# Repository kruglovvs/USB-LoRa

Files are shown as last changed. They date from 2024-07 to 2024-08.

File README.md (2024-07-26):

# USB-LoRa приёмопередатчик 
Это моя курсовая работа на 3 курсе МГТУ по направлению "Конструирование и технология электронных средств". Устройство передаёт данные между LoRa передачаей и USB COM терминалом.
Работает на основе микроконтроллера STM32WLE5CCU6. Имеет собственную PCB-антенну, разработанную в HFSS. Из-за малых габаритов антенна имеет плохой S-параметр и малую мощность, но вполне достаточную для LoRa передачи.
Габариты печатной платы соответсвуют распространённому дешёвому USB корпусу G1901C.

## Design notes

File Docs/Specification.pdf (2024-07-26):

Перв. примен.

ИУ4.11.03.03.21.63.14.001

Формат
Зона
Поз.
Обозначение | Наименование | Кол. | Примечание
| Документация
А3 | ИУ4.11.03.03.21.63.14.001 СБ | Сборочный чертёж
А3 | ИУ4.11.03.03.21.63.14.001 Э1 | Схема электрическая структурная
А3 | ИУ4.11.03.03.21.63.14.001 Э2 | Схема электрическая функциональная
А3 | ИУ4.11.03.03.21.63.14.001 Э3 | Схема электрическая принципиальная
А4 | ИУ4.11.03.03.21.63.14.001 ПЭ3 | Перечень элементов

Справ. N

А3 | ИУ4.11.03.03.21.63.14.001 ПД1 | Алгоритм работы устройства
А3 | ИУ4.11.03.03.21.63.14.001 ПД1 | Плакат демонстрационный
А2 | ИУ4.11.03.03.23.05.53.12.002 | Плата печатная

Детали

1 | ИУ4.11.03.03.23.05.53.12.002 | Плата печатная | 1

Прочие изделия

Чип-конденсаторы керамические

2 | К10-16В-5,1пФ1 ±5%(Murata, Япония) | 2 | С1,C2
3 | К10-16В-100нФ±10%(Murata, Япония) | 10 | C3,C16…С18,C25
Подп. и дата
C20…C23,C27
4 | К10-16В-4.7мкФ±10%(Murata, Япония) | 5 | C6,C12...C14
5 | К10-16В-47нФ±5%(Murata, Япония) | 1 | C4
6 | К10-16В-3.6пФ±5%(Murata, Япония) | 1 | C5
Инв. N дубл.
7 | К10-16В-68нФ±5%(Murata, Япония) | 3 | C7,C15,C30
8 | К10-16В-6.2пФ±5%(Murata, Япония) | 1 | C8
9 | К10-16В-4пФ±5%(Murata, Япония) | 1 | С9
Взаим. инв. N
10 | К10-16В-3.3пФ±5%(Murata, Япония) | 1 | С10
11 | К10-16В-2.4пФ±5%(Murata, Япония) | 2 | С11,C19
12 | К10-16В-0.47мкФ±10%(Murata, Япония) | 1 | C24

Подп. u дата

13 | К10-16В-33пФ±10%(Murata, Япония) | 3 | C26,C28,C29

ИУ4.11.03.03.21.63.14.001
Изм | Лист | № докум. | Подп. | Дата

Инв. N подп.

Разраб. Круглов В. С.

## LoRa-USB адаптер

спецификация

Лит. | Лист | Листов
Пров. | Чистяков М. Г. | 1 | 2
МГТУ им. Н. Э. Баумана
Кафедра ИУ4
Группа ИУ4-63Б

Н.контр.
Утв.

Формат
Зона
Поз.
Обозначение | Наименование | Кол. | Примечание
| Чип-резисторы толстоплёночные
14 | C2-0,125Вт-33Ом±10%(Yageo, Китай) | 2 | R1,R2
15 | С2-0,125Вт-10кОм±10%(Yageo, Китай) | 2 | R3,R4
16 | C2-0,125Вт-22кОм±10%(Yageo, Китай) | 1 | R5
17 | C2-0,125Вт-47кОм±10%(Yageo, Китай) | 3 | R6,R7,R8

Чип-индукторы многослойные

18 | LQG15HN2N6J (Murata, Япония) | 1 | L1
19 | LQG15HN11NJ (Murata, Япония) | 1 | L2
20 | LQG15HN47NJ (Murata, Япония) | 1 | L3
21 | LQG15HN1N8J (Murata, Япония) | 1 | L4
22 | LQG15HN7NJ (Murata, Япония) | 1 | L5
23 | LQG15HN150J (Murata, Япония) | 1 | L6
24 | Светодиоды
25 | TO-2106BC-MGD (OASISTEK, Китай) | 1 | VD1
| TO-2106BC-MRF (OASISTEK, Китай) | 1 | VD2

Подп. и дата

Микросхемы

26 | SRV05-4.TCT (Semtech, США) | 1 | DA1
Инв. N дубл.
27 | SRDA3.3-4DR2G (Onsemi, США) | DA2
28 | XC6219B332MR (UMW, Китай) | DA3
29 | HMC544AETR (Analog Devices, США) | DA4
Взаим. инв. N
30 | CP2102N-GQFN28R (Silicon Laboratories, США) | DD1
31 | STM32WLE5CCU6 (STMicroelectrionics, США) | DD2

Подп. u дата

32 | Кварцевый резонатор | ZQ1
33 | XRCGB16M000FXN02R0 (Murata, Япония) | XP1

Штекер USB-A PL-4 (Molex, США)

Инв. N подп.
ИУ4.11.03.03.21.63.14.001

Лист

2 Изм | Лист | № докум. | Подп. | Дата

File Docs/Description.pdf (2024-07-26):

Инв.№ подл. Подп.и дата Взам.инв.№ Инв.№ дубл. Подп. и дата

Формат A3 Справ.№ Перв.примен.

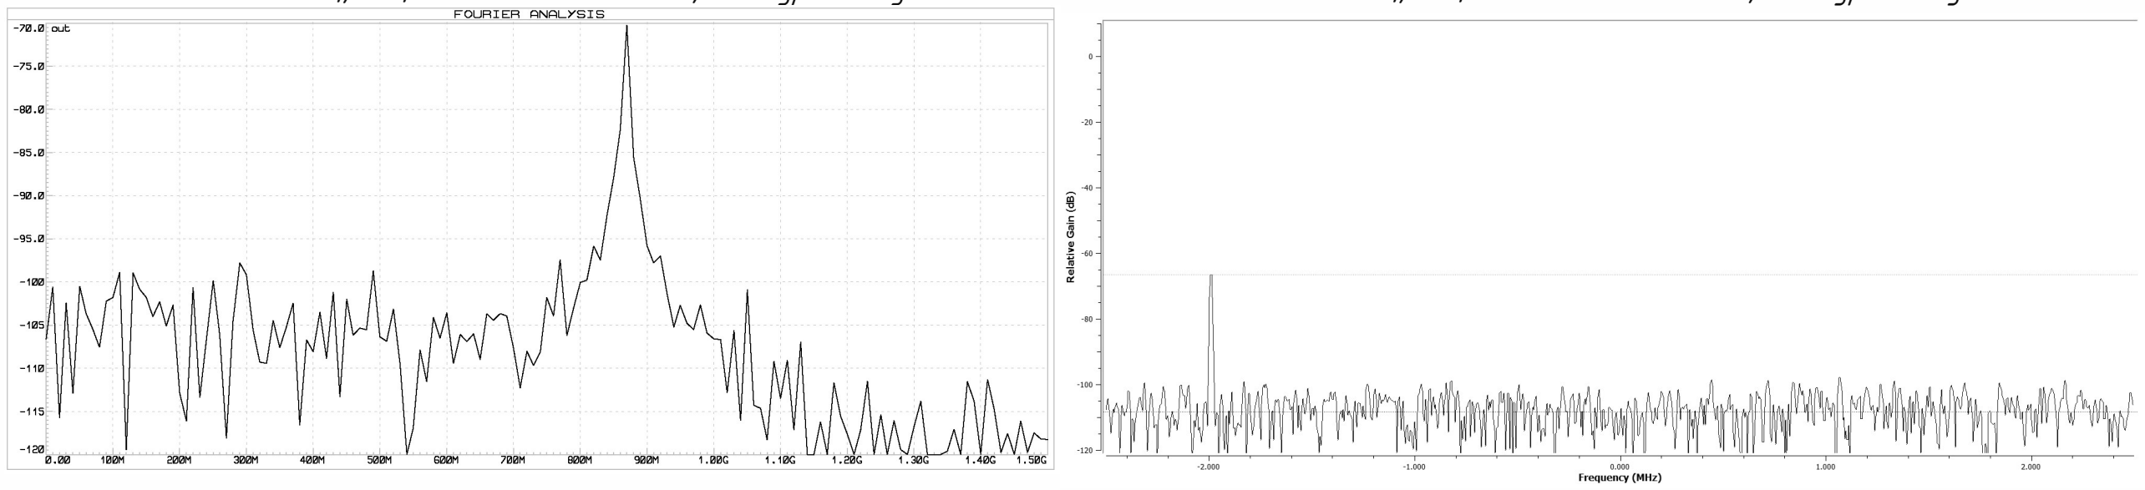
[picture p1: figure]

Н.контр.
Утв.
Копировал
| | | | | ИУ4.11.03.03.21.63.14.001 ПД2
| | | | | LoRa-USB адаптер Плакат демонстрационный | Лит. | Масштаб | Масса
Изм. | Лист | № докум. | Подп. | Дата
Разраб. | | Круглов В. С.
Пров. | | Чистяков М. Г.
Т.контр. | | | | | Лист | Листов 1
| | | | | МГТУ им. Н. Э. Баумана Кафедра ИУ4 Группа ИУ4-63Б

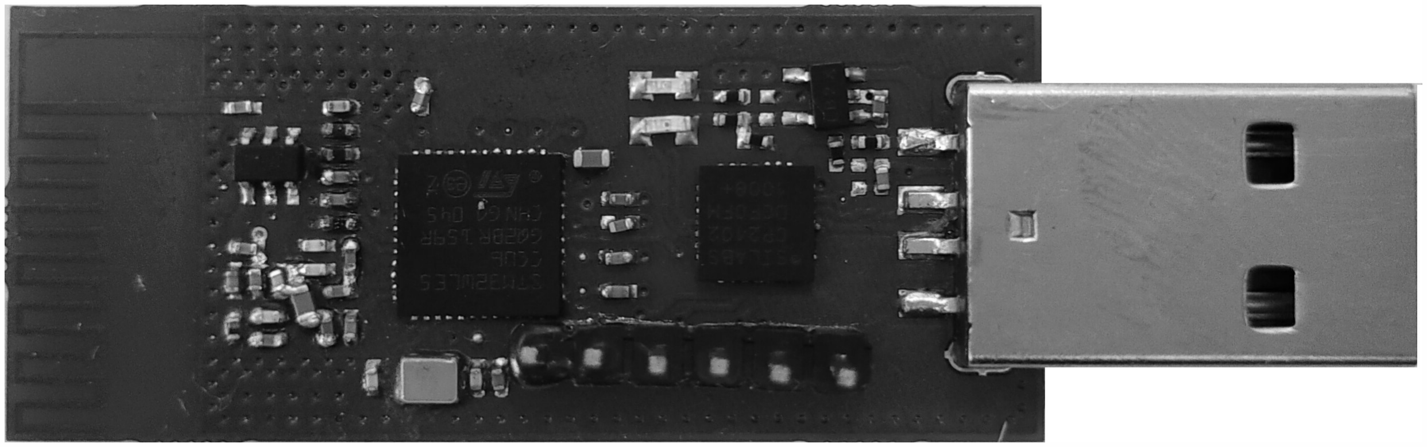
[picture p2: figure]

Итоговое устройство

Измеренная спектрограмма при отправке сигнала

через последовательный порт

## Вывод: результаты работы соответсвуют результатам моделирования, данные передаются между USB и LoRa, прототип соответсвует ТЗ

Частота сигнала 868МГц, мощность сигнала -70дБм, выше уровня шума на 30дБ Частота сигнала 868МГц, мощность сигнала -65дБм, выше уровня шума на 35дБ

Теоретическая спектрограмма при отправке сигнала
Диапазон 0...1500МГц | Ширина диапазона 5МГц, центральная частота 890 МГц, расстояние 1м

Для радиопередачи через LoRa достаточно,

## чтобы уровень сигнала была не ниже, чем на 20дБ уровня шума. Измеренный сигнал на

часототе 868МГц выше уровня шума на 35дБ,

## чего достаточно для передачи, что видно из вывода на терминале общения через последовательный порт

Окно терминала общения

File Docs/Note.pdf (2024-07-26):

Министерство науки и высшего образования Российской Федерации Федеральное государственное бюджетное образовательное учреждение высшего образования
«Московский государственный технический университет имени Н.Э. Баумана
(национальный исследовательский университет)» (МГТУ им. Н.Э. Баумана)
ФАКУЛЬТЕТ | «ИНФОРМАТИКА И СИСТЕМЫ УПРАВЛЕНИЯ» (ИУ)
КАФЕДРА | «ПРОЕКТИРОВАНИЕ И ТЕХНОЛОГИЯ ПРОИЗВОДСТВА ЭА» (ИУ4)

## РАСЧЕТНО-ПОЯСНИТЕЛЬНАЯ ЗАПИСКА

## К КУРСОВОЙ РАБОТЕ

## НА ТЕМУ:

## «Разработка, моделирование и экспериментальное исследование устройства LoRa-USB адаптера»

Студент | _________________ | Круглов В. С.
| (Подпись, дата)
Руководитель курсового проекта | _________________ | Чистяков М. Г.
| (Подпись, дата)

Москва, 2024

АННОТАЦИЯ

В рамках данной курсовой работы был разработан комплект

конструкторской документации для устройства «LoRa-USB адаптер». Описаны

принципы | работы | устройства, | обоснован | выбор | элементной | базы.

Спроектирована топология печатной платы в САПР Altium Designer 24 и

сборочный чертеж устройства. Проведено моделирование работы устройства в

САПР Proteus.

В результате работы получено полностью работоспособное устройство,

разработана принципиальная схема устройства, собран макетный образец,

проведены экспериментальные исследования его функциональных параметров и

сравнение параметров работы устройства с параметрами, полученными при

моделировании.

Ключевые слова: микроконтроллер, радиопередача, LoRa, USB, UART.

ABSTRACT

As part of this course work, a set of design documentation for the "LoRa-USB

adapter" device was developed. The principles of operation of the device are described,

the choice of the element base is justified. The topology of the printed circuit board in

CAD Altium Designer 24 and the assembly drawing of the device are designed. The

simulation of the device operation in the Proteus CAD is carried out.

As a result of the work, a fully functional device was obtained, a schematic

diagram of the device was developed, a mock-up sample was assembled, experimental

studies of its functional parameters were carried out and the parameters of the device

operation were compared with the parameters obtained during modeling.

Keywords: microcontroller, radiotraffic, LoRa, USB, UART.

СОДЕРЖАНИЕ

### 3 РАЗРАБОТКА СТРУКТУРНОЙ СХЕМЫ УСТРОЙСТВА “LORA-USB

### 4 РАЗРАБОТКА ФУНКЦИОНАЛЬНОЙ СХЕМЫ «LORA-USB АДАПТЕР»

### 8 РАЗРАБОТКА СБОРОЧНОГО ЧЕРТЕЖА И СПЕЦИФИКАЦИИ

9 | РАЗРАБОТКА | ПРОГРАММНОГО | ОБЕСПЕЧЕНИЯ“LORA-USB

УСЛОВНЫЕ ОБОЗНАЧЕНИЯ, СОКРАЩЕНИЯ И ТЕРМИНЫ

ГОСТ | − Государственный стандарт
ВАХ | − Вольт-амперная характеристика
КМО | − Компонент, монтируемый в отверстия
КМП | − Компонент, монтируемый на поверхности
ДПП | − Двухсторонняя печатная плата
МК | − Микроконтроллер
САПР | − Система автоматизированного проектирования
ОУ | − Операционный усилитель
ПК | − Персональный компьютер
ПО | − Программное обеспечение
ПП | − Печатная плата
СБ | − Сборочный чертеж
СП | − Спецификация
УГО | − Условное графическое обозначение
ШИМ | − Широтно-импульсная модуляция
ЭРЭ | − Электрорадиоэлементы

ВВЕДЕНИЕ

Работа посвящена разработке и исследованию устройства «LoRa-USB

адаптер».

«LoRa-USB адаптер» - электрический прибор, который позволяет

передавать данные, получаемые по USB, через LoRa связь.

Целью работы является LoRa-USB адаптера на базе микроконтроллера,

разработка | комплекта | конструкторской | документации, | а | также

экспериментальное исследование устройства для выявления его пригодности к

эксплуатации.

Для достижения поставленных целей в работе был решен следующий

комплекс задач:

− разработка алгоритма работы устройства;

− написание программного кода;

− отладка программного кода;

− разработка схемы электрической структурной;

− разработка схемы электрической принципиальной;

− моделирование схемы с использованием схемотехнической САПР;

− разработка топологии печатной платы и создание чертежей;

− сборка макетного образца устройства;

− экспериментальные исследования работы устройства и ПО.

Исходными данными для работы являются:

− задание на выполнение курсового проекта;

− календарный план выполнения курсового проекта.

Результатами работы являются:

− расширенное техническое задание;

− схема электрическая структурная (Э1);

− схема электрическая принципиальная (Э3);

− перечень элементов;

− чертеж печатной платы;

− сборочный чертеж;

− спецификация;

− алгоритм работы устройства (ПД1);

− плакат демонстрационный (ПД2) сравнения результатов моделирования и

эксперимента;

− разработанный опытный образец;

− расчетно-пояснительная записка (РПЗ).

Структура и объем работы: Работа состоит из 48 страниц, включает

список основных понятий, введение, 10 глав, заключение, список используемых

источников и перечень приложений.

### 1 АНАЛИЗ УСТРОЙСТВА “LORA-USB АДАПТЕР”

В результате анализа существующих решений была выявлена структура

устройства LoRa-USB адаптеров, основанная на микроконтроллере, содержащем

модуль LoRa приёмопередатчика, и USB-UART моста.

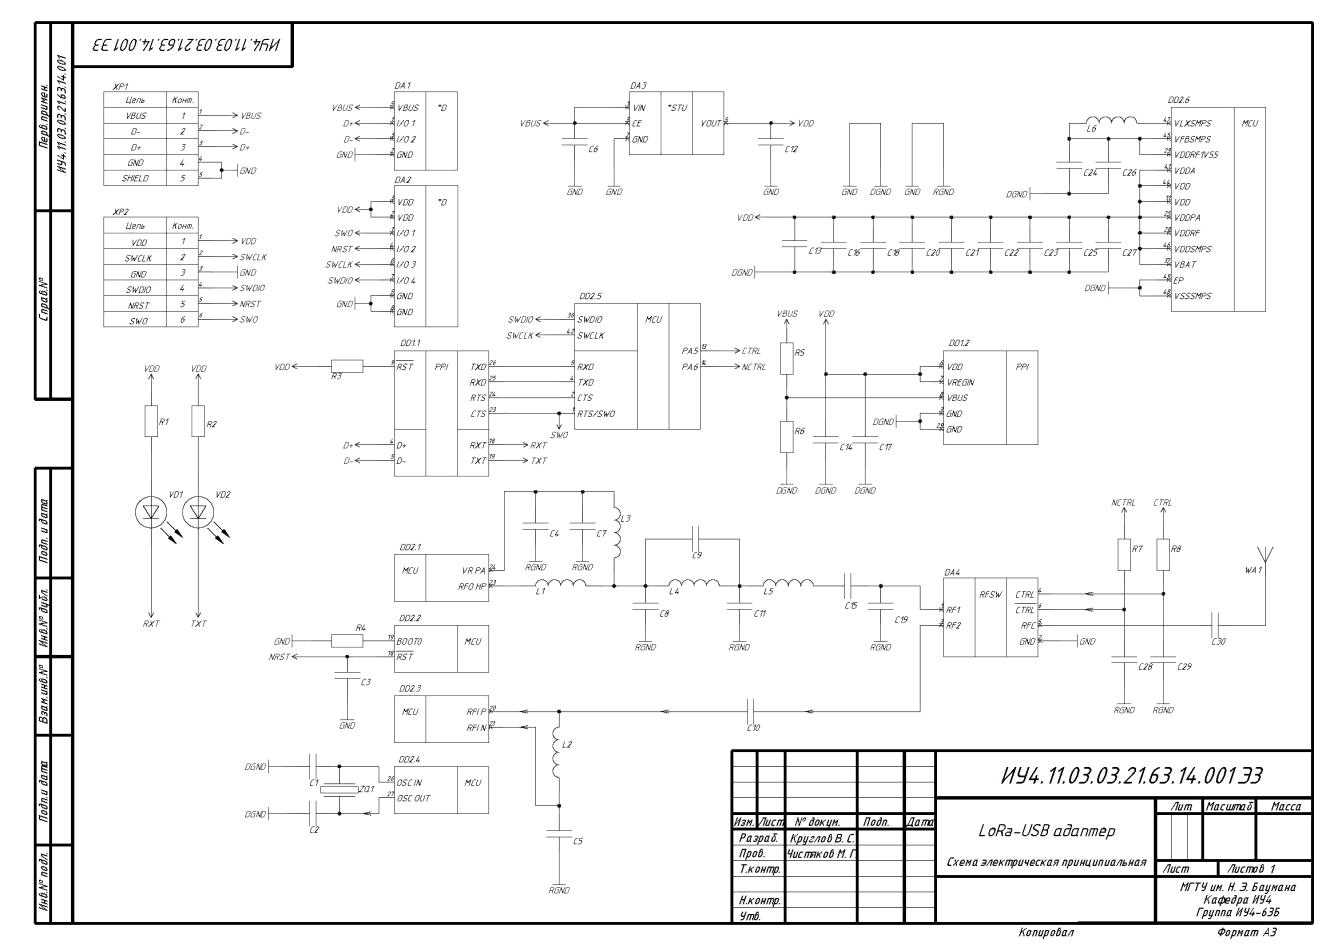
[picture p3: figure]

Рисунок 1.1 – Схема устройства LoRa-USB адаптера

Рассмотрим работу данной схемы. USB-UART мост преобразует данные из

USB в UART для передачи на микроконтроллер, который их передаёт через LoRa

модуляцию на антенну.

### 2 РАЗРАБОТКА ТЕХНИЧЕСКОГО ЗАДАНИЯ

Согласно техническому заданию, должно быть разработано LoRa-USB

адаптера с использованием LoRa приёмопередатчика и USB-UART моста.

Для обеспечения стабильной работы устройства необходим источник

питания 3,3В для цифровых микросхем. Было выбрано решение в виде

использования понижающего стабилизатора напряжения с 5 В от USB до 3.3 В.

Таким образом в разработанном техническом задании были сделаны

следующие требования к конструкции изделия:

− Номинальное выходное напряжение: 3.3В±5% (постоянное).

− Питание через порт USB.

− Антенна частотой 868МГц и импедансом 50 Ом.

− Импеданс дорожек радиопередачи 50 Ом.

− Максимальный ток потребления 500мА.

− Вывод информации через USB.

− Световая индикация при передаче данных по USB.

− Тактовая частота микроконтроллера 32МГц.

− Объем памяти микроконтроллера, занимаемый прошивкой не более

256 кБайт.

− Рабочий температурный диапазон: -20…+55ºС

Вывод

В данном разделе были синтезированы и обоснованы основные

технические требования к разрабатываемому устройству. В результате синтеза

получились требования, позволяющие разработать устройство с использованием

микроконтроллера и USB-UART моста, которые будет легко программироваться

и отлаживаться.

### 3 РАЗРАБОТКА СТРУКТУРНОЙ СХЕМЫ УСТРОЙСТВА

“LORA-USB АДАПТЕР”

Разработка | схемы | электрической | структурной | (Э1) | предполагает

первоначальную оценку работы и выделение основных структурных частей, из

которых состоит устройство LoRa-USB адаптер. Структурная схема была

разработана согласно ГОСТ 2.701-2008. В качестве среды разработки была

выбрана программа «Altium Designer». Структурная схема устройства

представлена на рисунке 3.1, а также на чертеже ИУ4.11.03.03.21.63.14.001 Э1.

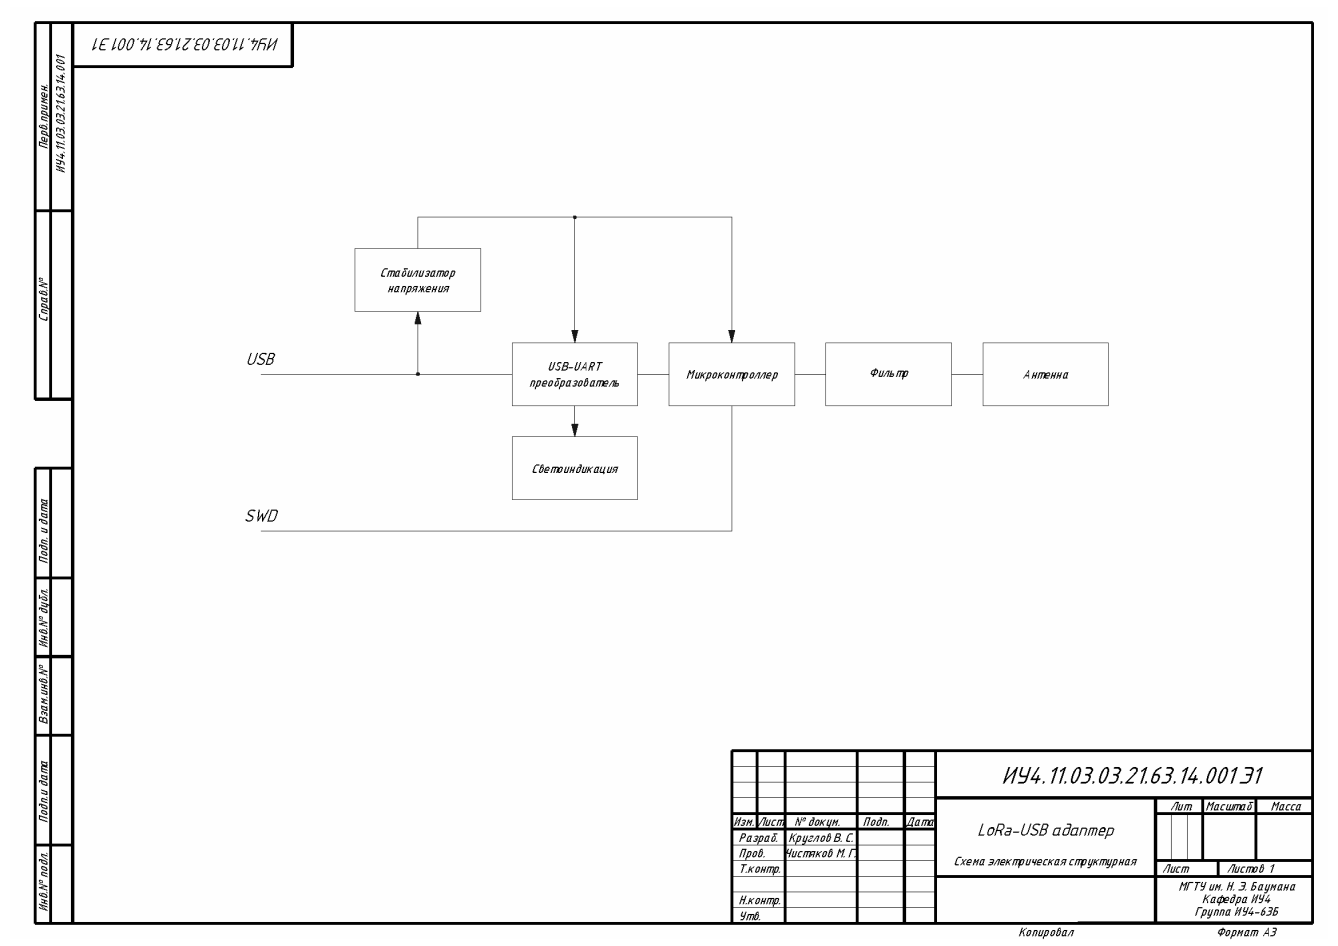
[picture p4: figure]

Рисунок 3.1 - Схема электрическая структурная устройства LoRa-USB адаптера

Устройство можно разделить на несколько основных частей:

− Стабилизатор напряжения.

− Микроконтроллер.

− USB-UART преобразователь.

− Фильтр.

− Антенна.

Линейный стабилизатор напряжения нужен для подачи напряжения

микроконтроллеру и USB-UART мосту, для их стабильной и безопасной работы.

В качестве микроконтроллера был выбран 32-битный микроконтроллер

STM32WLE5CCU6, который содержит встроенный LoRa приёмопередатчик и

малые габариты, а также UART модуль.

В качестве USB-UART модуля выбран CP2102N, т.к. имеет малые

габариты и выводы для светоиндикации. Вывод

В данном разделе была разработана структурная схема устройства LoRa-

USB адаптера. Оформлена по ГОСТ 2.701-2008 в пакете «Altium Designer».

Были описаны причины использования именно такой структурной схемы.

Упомянуты выбранные элементы на каждую позицию. Произведено описание

работы устройства в контексте представленной структурной схемы устройства.

### 4 РАЗРАБОТКА ФУНКЦИОНАЛЬНОЙ СХЕМЫ «LORA-USB

АДАПТЕР»

Разработка схемы электрической функциональной (Э2) предполагает

первоначальную оценку работы и выделение основных функциональных частей,

из которых состоит устройство. Функциональная схема была разработана

согласно ГОСТ 2.701-2008. В качестве среды разработки была выбрана

программа «Solid Edge». Функциональная схема устройства представлена на

рисунке 4.1, а также на чертеже ИУ4.11.03.03.21.63.14.001 Э2.

Рисунок 4.1 - Схема электрическая функциональная устройства

Устройство можно разделить на несколько основных частей:

− Стабилизатор напряжения.

− Микроконтроллер.

− USB-UART преобразователь.

− Фильтр для отправляемого сигнала.

− Фазорасщепитель принимаемого сигнала.

− СВЧ-реле.

− Полосовой фильтр.

− Антенна.

− Светоиндикация

Линейный стабилизатор напряжения XC6219B332MR нужен для

подачи напряжения микроконтроллеру и USB-UART мосту, для их стабильной и

безопасной работы.

В качестве микроконтроллера был выбран 32-битный микроконтроллер

STM32WLE5CCU6, который содержит встроенный LoRa приёмопередатчик и

малые габариты, а также UART модуль.

В качестве СВЧ-реле выбрана микросхема HMC544AETR, т.к. имеет

малые габариты и управляется напряжением со всего 2 входов.

В качестве USB-UART модуля выбран CP2102N, т.к. имеет малые

габариты и выводы для светоиндикации.

Вывод

В данном разделе была разработана функциональная схемы устройства

LoRa-USB адаптера. Оформлена по ГОСТ 2.701-2008 в пакете «Solid Edge».

Были описаны причины использования именно такой структуры. Упомянуты

выбранные элементы на каждую позицию. Произведено описание работы

устройства в контексте представленных структурной и функциональной схем

устройства.

5 МОДЕЛИРОВАНИЕ УСТРОЙСТВА “LORA-USB АДАПТЕР”

Целью | данного | раздела | является | моделирование | аналоговых

составляющих разрабатываемого устройства LoRa-USB адаптера.

Моделирование фильтров производилось в программах «Proteus». Схема

модели представлена на рисунке 5.1.

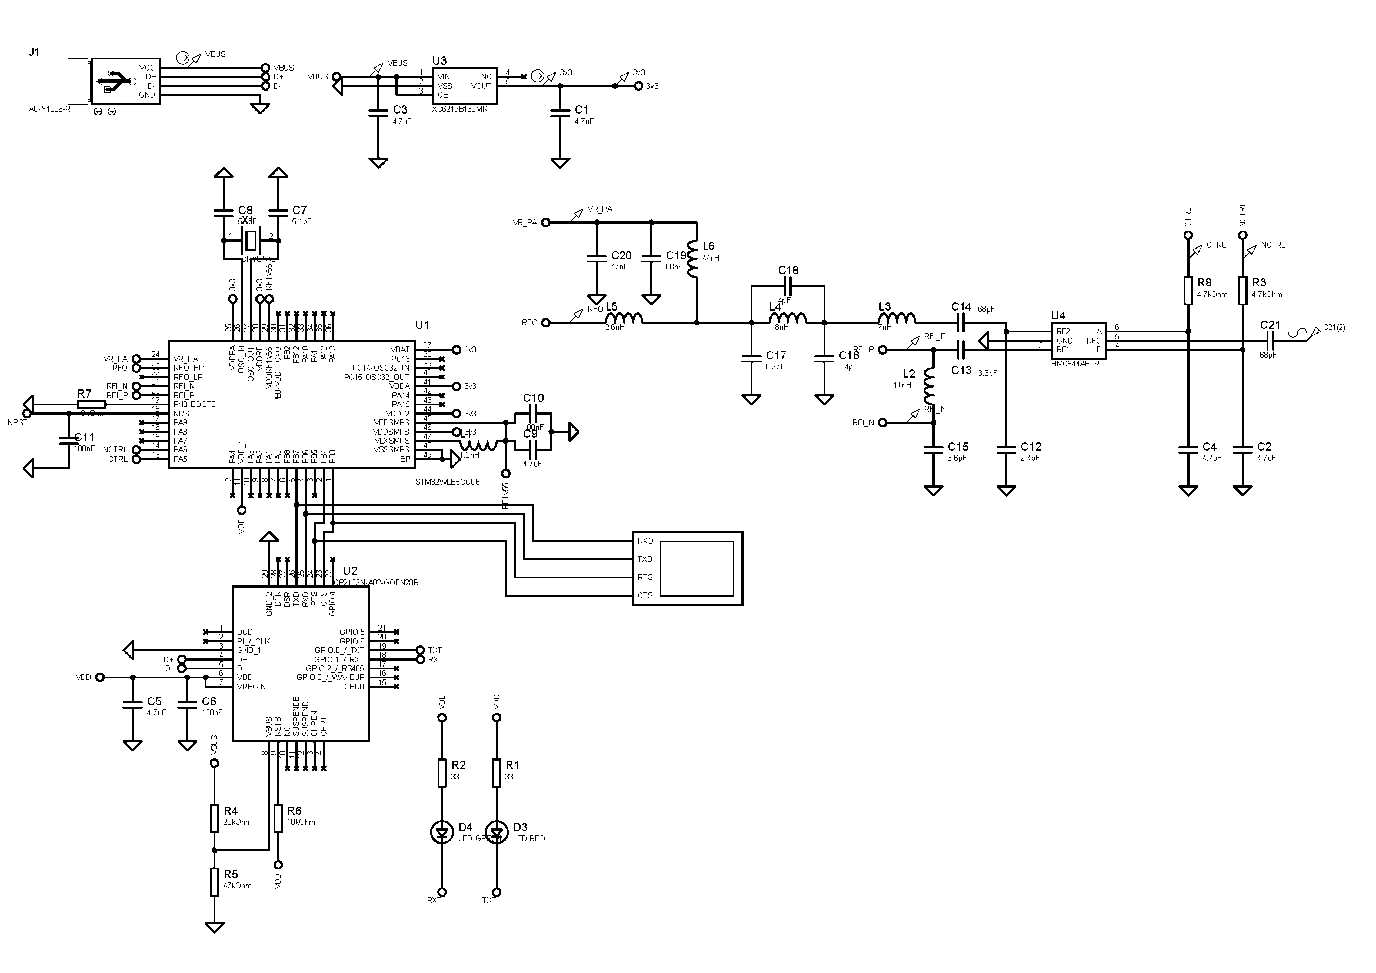
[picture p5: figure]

Рисунок 5.1 – Схема модели

Для определения работоспособности схемы необходимо проверить

передачу информации от USB через преобразователь интерфейса до

микроконтроллера, разницу фаз на входах дифференциальной пары RFI_P,

RFI_N, коэффициент передачи радиосигнала через фильтр в направлении

отправки и приёма

На следующих графиках представлены результаты моделирования

радиосигнала при различных значениях частоты сигнала: коэффициент передачи

при отправке (рисунок 5.2); коэффициент передачи на входах RFI_N, RFI_P

(рисунок 5.3); фазы на входах RFI_N, RFI_P (рисунок 5.4).

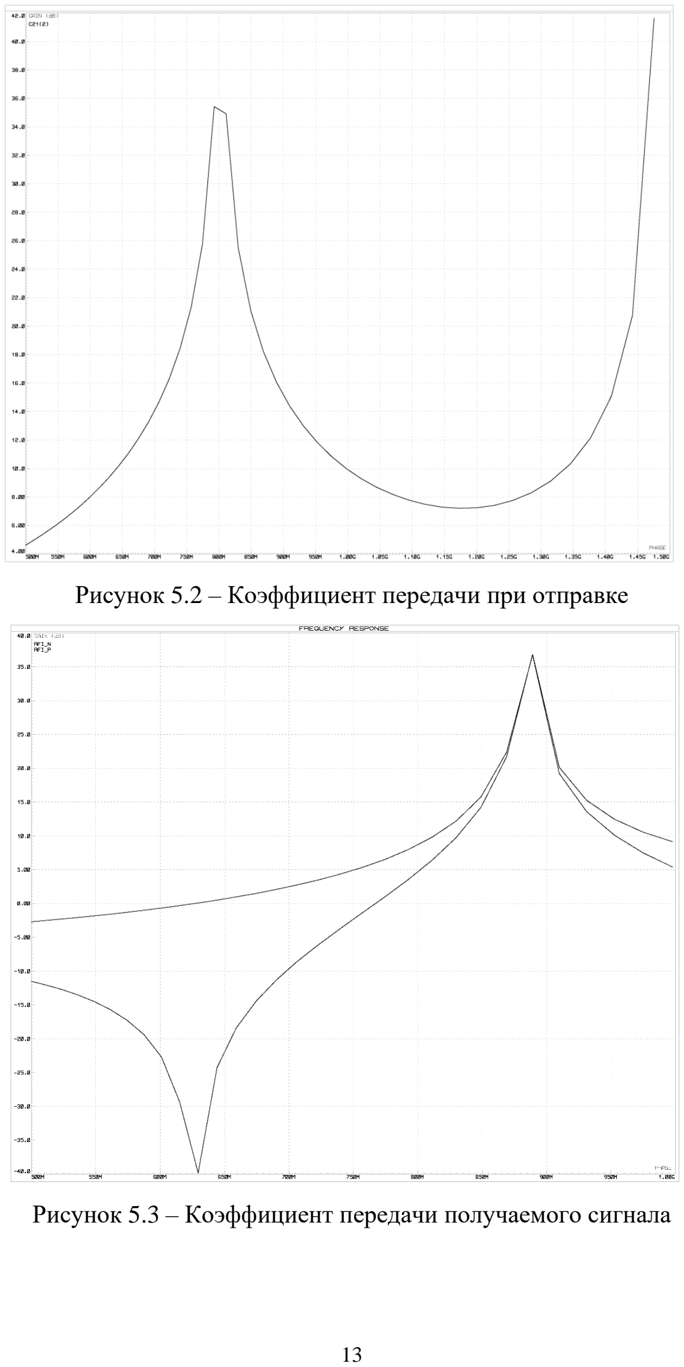
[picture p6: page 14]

Рисунок 5.2 – Коэффициент передачи при отправке

Рисунок 5.3 – Коэффициент передачи получаемого сигнала

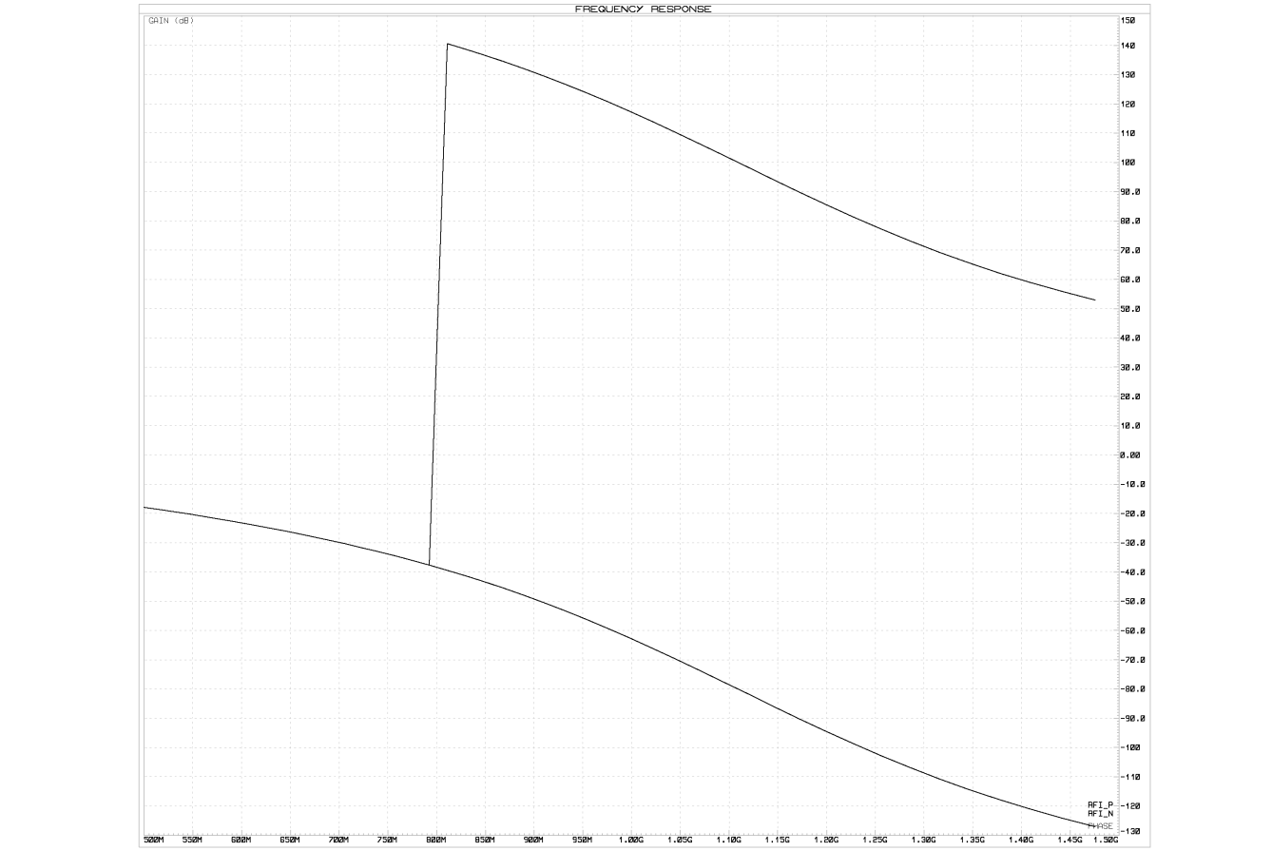
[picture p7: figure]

Рисунок 5.3 – Фазы RFI_N, RFI_P

По графикам видно, что пик передаточной характеристики при отправке

соответствует частоте 800МГц, а при необходимой частоте 868МГц усиление в

19дБ. При приёме сигнала равность мощностей дифсигналов достигается при

частоте 868МГц, а противофаза сигналов при частотах выше 800МГц.

Тип антенны для уменьшения габаритов выбран планарный в виде

проводника на печатной плате (рисунок 5.4). Проектирование и моделирование

антенны проведено в программе “Ansys HFSS”. С помощью эволюционной

оптимизации по минимуму пика S-параметра получены параметры толщины

проводников, шага между витками меандра и т.д.

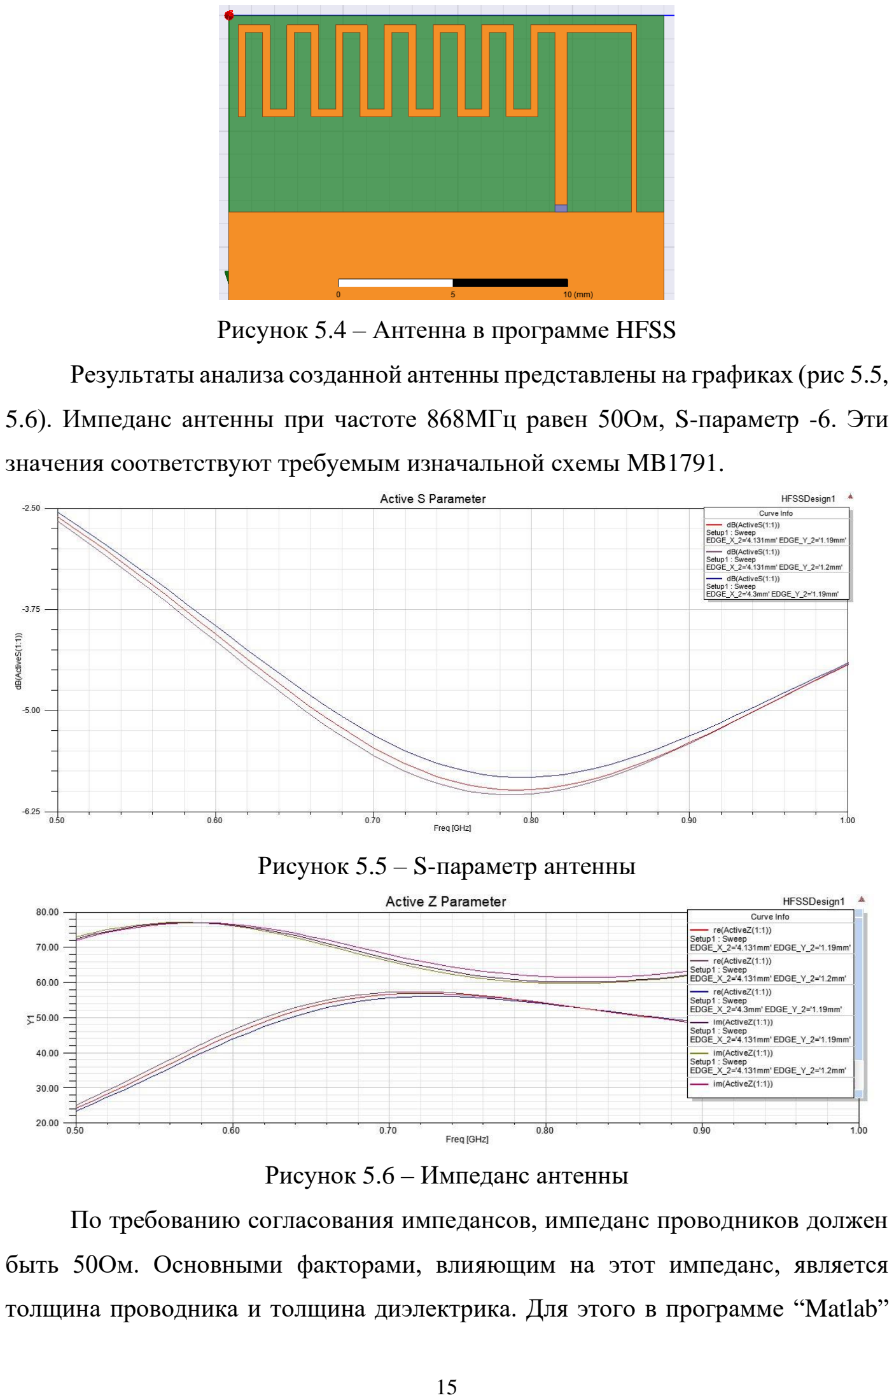
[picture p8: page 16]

Рисунок 5.4 – Антенна в программе HFSS

Результаты анализа созданной антенны представлены на графиках (рис 5.5,

5.6). Импеданс антенны при частоте 868МГц равен 50Ом, S-параметр -6. Эти

значения соответствуют требуемым изначальной схемы MB1791.

Рисунок 5.5 – S-параметр антенны

Рисунок 5.6 – Импеданс антенны

По требованию согласования импедансов, импеданс проводников должен

быть 50Ом. Основными факторами, влияющим на этот импеданс, является

толщина проводника и толщина диэлектрика. Для этого в программе “Matlab”

(рисунок 5.7) рассчитаны параметры проводников при используемой в плате

толщине диэлектрика 300мкм (плата многослойная). Требуемая толщина –

530мкм.

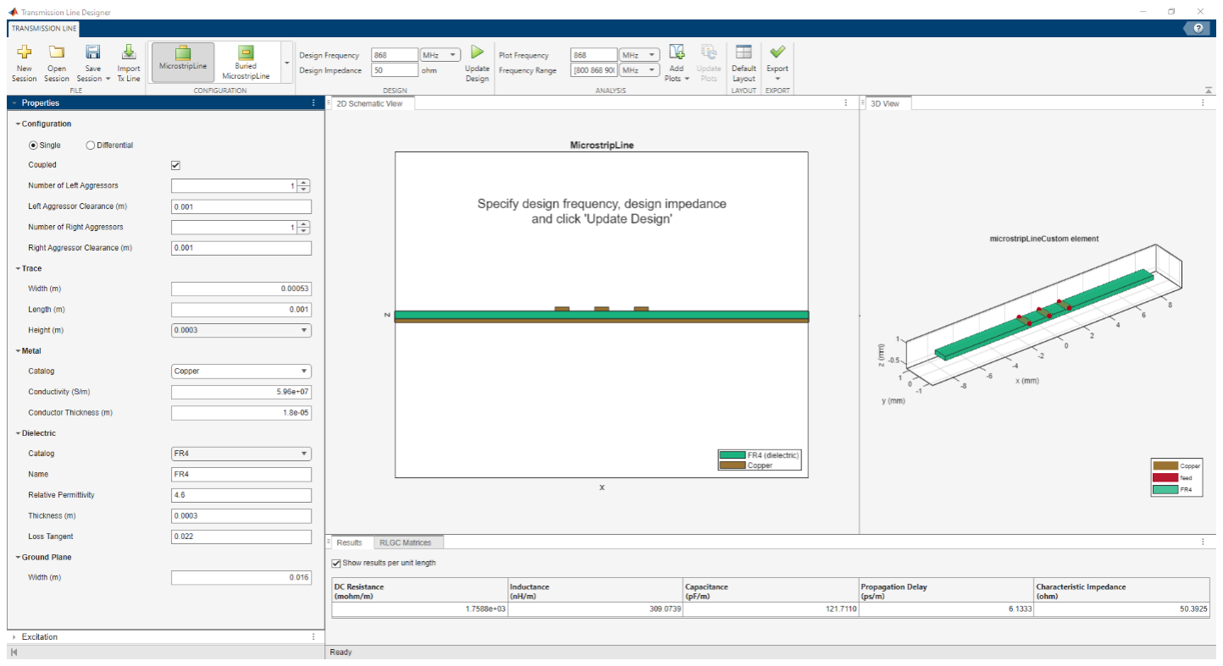
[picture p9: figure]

Рисунок 5.7 – Импеданс дорожек

Таким образом достигается согласование импедансов в радиочасти для

увеличения мощности сигнала.

Вывод

В данном разделе было проведено моделирование работы аналоговой

части устройства. Таким образом, при верном подборе цифровых компонентов

устройство будет функционировать согласно заявленным характеристикам.

### 6 РАЗРАБОТКА ПРИНЦИПИАЛЬНОЙ СХЕМЫ

### 6.1 Разработка принципиальной схемы устройства LoRa-USB адаптера

Схема электрическая принципиальная (Э3) устройства была разработана

согласно ГОСТ 2.701-2008 и ГОСТ 2.702-2011 на основе анализа

электрической структурной схемы (Э1) (рисунок 3.1). Разработанная схема

электрическая принципиальная (Э3) LoRa-USB адаптера представлена

на рисунке 6.1. и на чертеже ИУ4.11.03.03.21.63.14.001 Э3. В качестве среды

разработки была выбрана САПР «Altium Designer».

Рисунок 6.1 – Схема электрическая принципиальная устройства LoRa-USB

адаптер

Рассмотрим принцип работы приведенной схемы. Начнем с питания

схемы. Устройство питается от вывода 1 выхода XP1, который является выходом

разъема USB-штекера. Напряжение 5 вольт с этого вывода поступает на вход

стабилизатора напряжения DA3, на выходе которого формируется 3.3 В, что

необходимо для питания микроконтроллера. Также диодные сборки DA1 и DA2 защищают устройство от статического заряда. Для корректной работы

стабилизатора напряжения используются конденсаторы С6 и С12.

После обеспечения напряжением всех узлов системы устройство выходит

в рабочий режим. USB-UART преобразователь DD1 передаёт данные между USB

штекером и UART модулем микроконтроллера, для чего имеет делитель

напряжения резисторами R5 и R6 от 5В до 3.3В опорного напряжения,

разграничивающего биты 0 и 1 данных. Выход XP2 предназначен для

программирования микроконтроллера.

Для обеспечения корректной работы всей периферии микроконтроллера

необходимо схемотехнически решить проблему возникновения помех от работы

самого микроконтроллера и USB-UART моста. Для этого используются

конденсаторы C13, C16, C18, C20-C23, C25, C27, C14, C17 для каждого вывода

питания, которые представляют собой фильтры низких частот, что качественно

сказывается на количестве помех выбрасываемыми цифровыми схемами на

линию питания. Также для питания радиочасти требуются низкочастотные

фильтры из L6, C24, C26

Для корректной работы микроконтроллера вывод RESET необходимо

подключить параллельно конденсатору, для того чтобы шумы от питания не

сбросили ход работы устройства. R7, C28 и R8, C28 – низкочастотные фильтры

для предотвращения самопроизвольного переключения под влиянием шумов

радиочасти.

В радиочасти конденсаторы C15, C30 – блокирующие; L2, C6 –

фазорасщепитель, дающий сдвиг фаз 180 градусов при частоте выше 800МГц;

L1 и C8 – LC согласующая цепь импеданса; C9 – фильтр второй гармоники; L4,

C11 – согласуют импеданс; L5, C11, C19 – низкочастотный фильтр.

### 6.2 Обоснование работы устройства

Питание на плату подается через порт для загрузки прошивки в

микроконтроллер (ХР2). Питание идет USB через соответствующий переходник

и составляет 5В.

Цепь, содержащая DA3 является цепью стабилизации питания, на выходе

которой 3.3В, необходимые для работы микроконтроллера. Цепь VD1, VD2 –

цепь индикации работы устройства.

Цепь RFI_N, RFI_P – цепь входа радиосигнала. На нее идет сигнал в

соответствии с программой, заданной МК. Отправка данных проходит через

цепь VR_PA и RFO_HP.

### 6.3 Обоснование выбора элементной базы

В | качестве | управляющего | устройства | был | выбран | 32-битный

микроконтроллер STM32WLE5CCU6 (DD2). Выбор был сделан на основе ТЗ.

Цоколевка и размеры корпуса микроконтроллера UFQFPN-48 приведены

на рисунке 6.3.1.

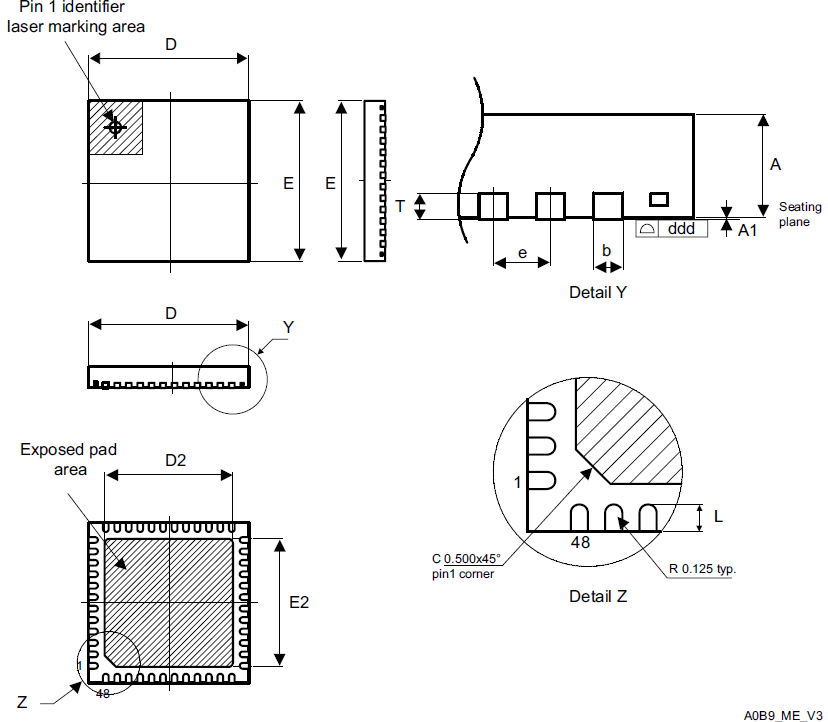
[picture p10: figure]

Рисунок 6.3.1 – Цоколевка и размеры микроконтроллера STM32WLE5CCU6

Технические характеристики выбранного микроконтроллера:

− Напряжение питания: 1.8…3.6 В.

− Ширина шины данных: 32-бит.

− Тактовая частота до 48 МГц.

− Объем flash памяти 256 кБайт.

− Объем RAM памяти 64 кБайт.

− Встроенные интерфейсы: UART, SPI, I2C, LoRa.

− Частота радиочасти 150…960 МГц.

Для преобразования 5 В входного питания в 3,3 В и для стабильного

поддержания данного напряжения был выбран стабилизатор XC6219B332MR

(DA3). Цоколевка и размеры корпуса регулятора напряжения SOT-23-5

представлены на рисунке 6.1.2.

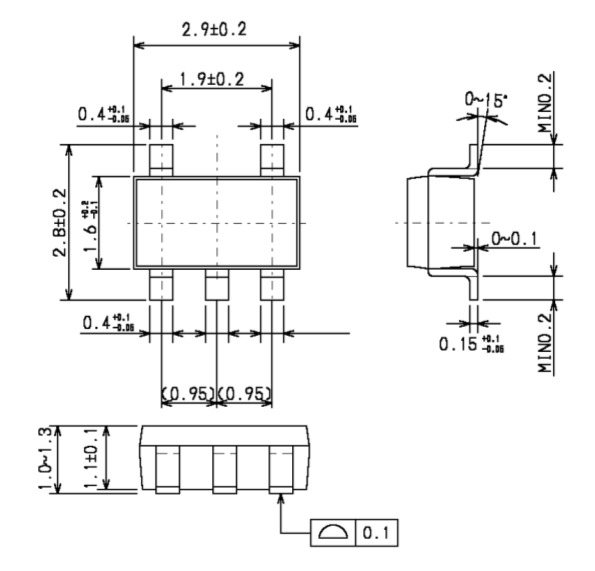
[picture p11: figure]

Рисунок 6.3.2 – Цоколевка и размеры стабилизатора напряжения

XC6219B332MR

Как описывалось ранее стабилизатор напряжения нужен для обеспечения,

требуемого микроконтроллером напряжения.

Технические характеристики выбранного стабилизатора:

− полярность положительная

− тип выхода фиксированный

− максимальный ток нагрузки 300 мА

− максимальное входное напряжение 6 В

− диапазон рабочих температур -40…+85

оС.

Конденсаторы в схеме необходимы для стабильной работы и подавления

помех на различных устройствах, а также в схемах фильтров радиочасти. В качестве конденсаторов для подавления помех на стабилизаторе питания (С6,

С12) выбраны керамические конденсаторы X5R номиналом 100 нФ и 10 мкФ, с

рабочим напряжением 16 В. Для стабильной работы микроконтроллера были

выбраны керамические конденсаторы X5R номиналом 10 мкФ и 0.1 мкФ

соответственно.

Цоколевка и размеры корпуса конденсаторов представлены на рисунке

6.3.3.

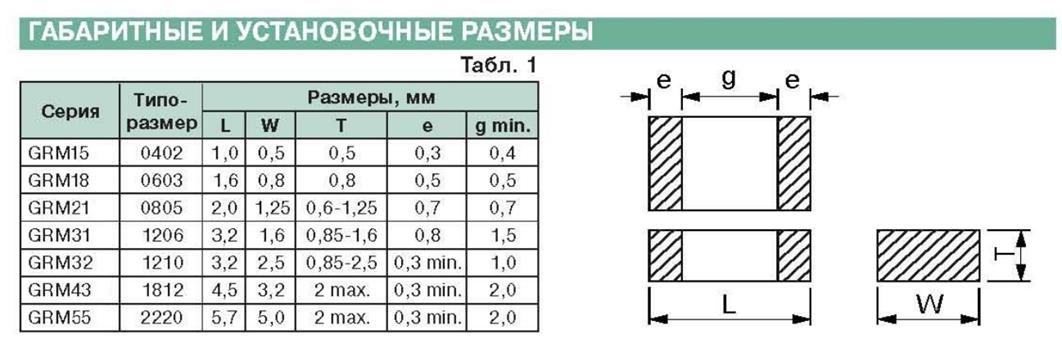
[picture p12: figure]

Рисунок 6.3.3 – Цоколевка и размеры конденсаторов

Основные технические характеристики конденсаторов:

− типоразмер 0402.

− рабочее напряжение от 16 до 50 В.

− допуск номинала 5%.

− диапазон рабочих температур -55…+125оС.

В качестве индукторов (L1-L6) были выбраны многослойные индукторы,

которые предназначены для работы в цепях переменного тока. Используются для

поверхностного монтажа.

Цоколевка и размеры корпуса резисторов представлены на рисунке 6.3.4.

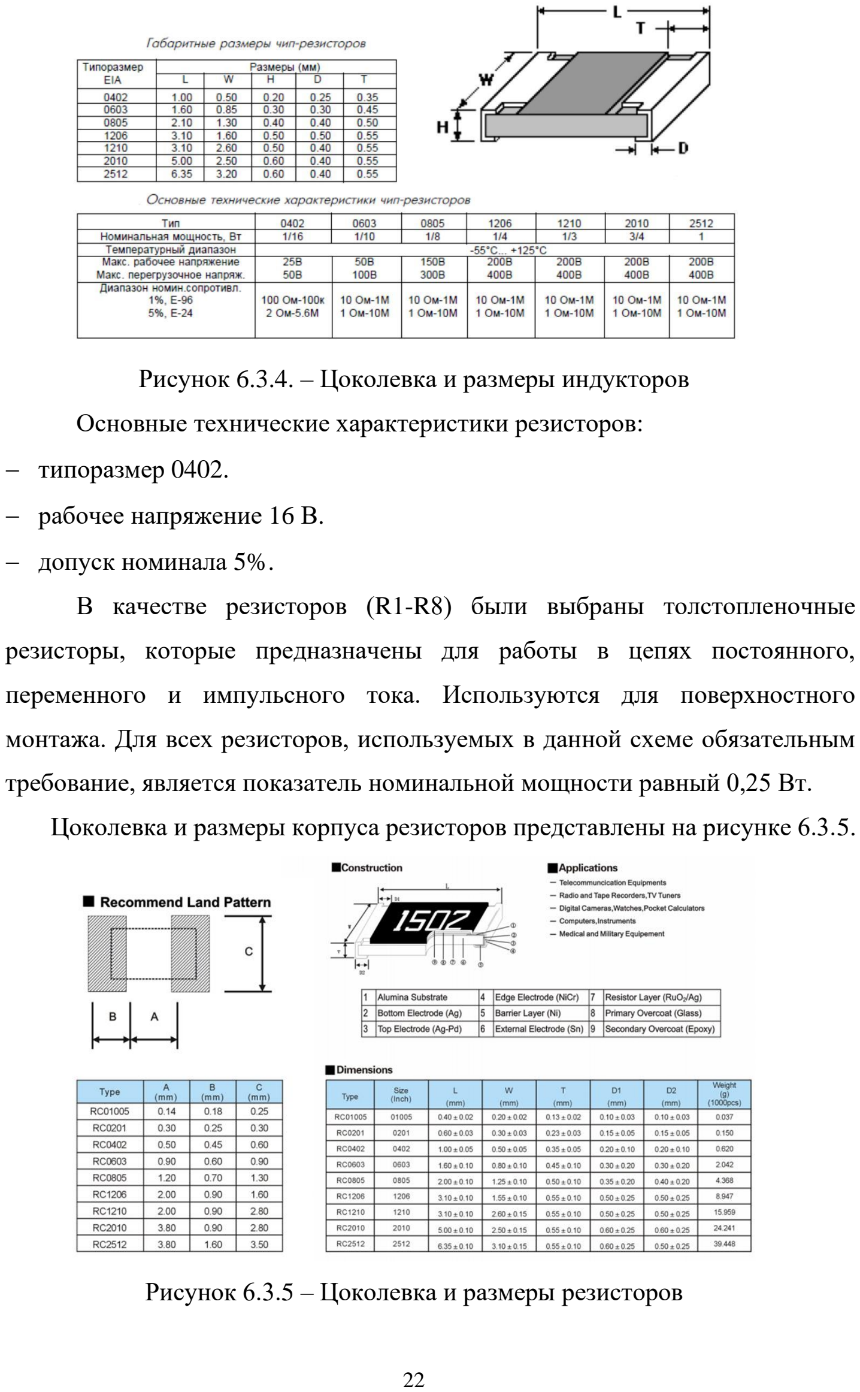
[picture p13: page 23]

Рисунок 6.3.4. – Цоколевка и размеры индукторов

Основные технические характеристики резисторов:

− типоразмер 0402.

− рабочее напряжение 16 В.

− допуск номинала 5%.

В качестве резисторов (R1-R8) были выбраны толстопленочные

резисторы, которые предназначены для работы в цепях постоянного,

переменного и импульсного тока. Используются для поверхностного

монтажа. Для всех резисторов, используемых в данной схеме обязательным

требование, является показатель номинальной мощности равный 0,25 Вт.

Цоколевка и размеры корпуса резисторов представлены на рисунке 6.3.5.

Рисунок 6.3.5 – Цоколевка и размеры резисторов

Основные технические характеристики резисторов:

− типоразмер 0402.

− рабочее напряжение 200 В.

− допуск номинала 5%.

− номинальная мощность 0.25 Вт.

В качестве USB-UART моста (DD1) был выбран CP2102N-A02-

GQFN28R. Внешний вид и цоколевка представлены на рисунке 6.3.6.

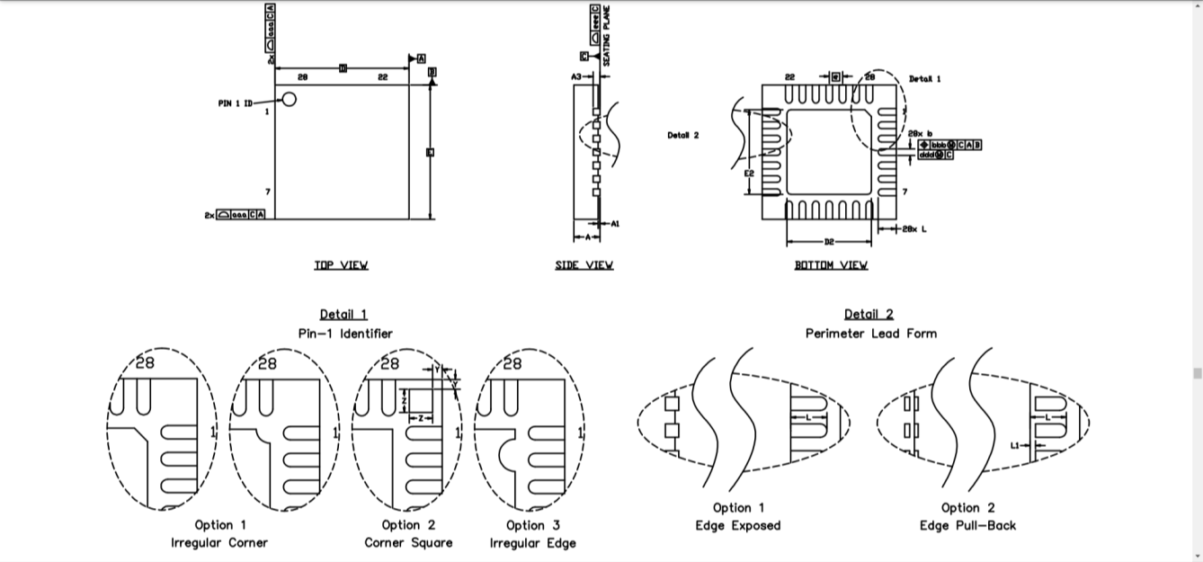
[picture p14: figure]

Рисунок 6.3.6 - Цоколевка и размеры CP2102N

Основные технические характеристики кнопки тактовой CP2102N-A02-

GQFN28R:

− Рабочее напряжение 3.3 В.

− Буфер данных 512 байт.

В качестве разъема для прошивки микроконтроллера (XP2) были

выбраны штыревые вилки типа PLS-6. Внешний вид и цоколевка штыревой

вилки типа PLS представлены на рисунке 6.3.7.

Рисунок 6.3.7 - Цоколевка и размеры штыревой вилки

В качестве разъема для подключения к USB порту компьютера (XР3)

был выбран разъем USB type A. Внешний вид и цоколевка разъема представлены

на рисунке 6.3.8.

Рисунок 6.3.8 - Цоколевка и размеры разъема USB type A

В качестве СВЧ-реле (DA4) выбран HMC544AETR. Внешний вид и

цоколевка разъема представлены на рисунке 6.3.9.

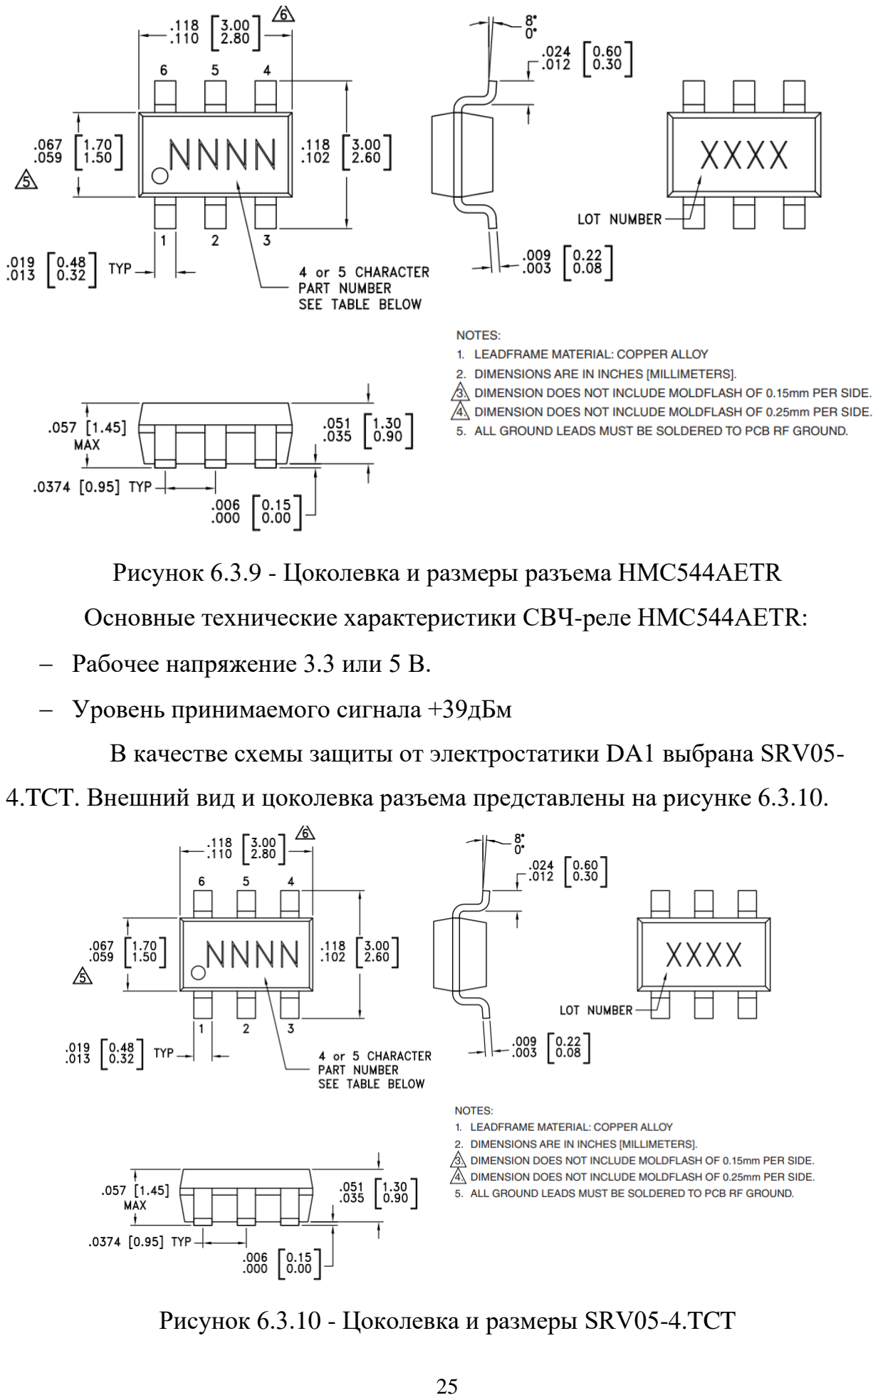
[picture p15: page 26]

Рисунок 6.3.9 - Цоколевка и размеры разъема HMC544AETR

Основные технические характеристики СВЧ-реле HMC544AETR:

− Рабочее напряжение 3.3 или 5 В.

− Уровень принимаемого сигнала +39дБм

В качестве схемы защиты от электростатики DA1 выбрана SRV05-

4.TCT. Внешний вид и цоколевка разъема представлены на рисунке 6.3.10.

Рисунок 6.3.10 - Цоколевка и размеры SRV05-4.TCT

Основные технические характеристики SRV05-4.TCT:

− Пиковый ток 12 А.

− Максимальное обратное напряжение 5 В.

В качестве схемы защиты от электростатики DA2 выбрана SRDA3.3-

4DR2G. Внешний вид и цоколевка разъема представлены на рисунке 6.3.11.

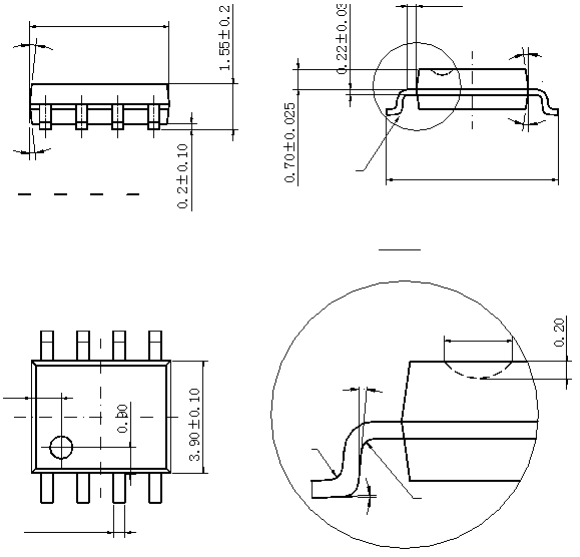
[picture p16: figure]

Рисунок 6.3.11 - Цоколевка и размеры SRDA3.3-4DR2G

Основные технические характеристики SRDA3.3-4DR2G:

− Пиковый ток 12 А.

− Максимальное обратное напряжение 5 В.

Для зелёных светодиодов при токе 20 мА упадет 2 В, тогда

сопротивление резистора будет равно

Rк =

3.3 − 2
0.02 = 65 Ом (берем 68 Ом)

### 6.4 Разработка перечня элементов (ПЭ3)

После выбора элементной базы был составлен перечень элементов схемы

(ПЭ3) согласно ГОСТ 2.701-2008. Перечень элементов ПЭ3) представлен на

рисунках 6.4.1, 6.4.2., а также документом ИУ4.11.03.03.21.63.14.001 ПЭ.

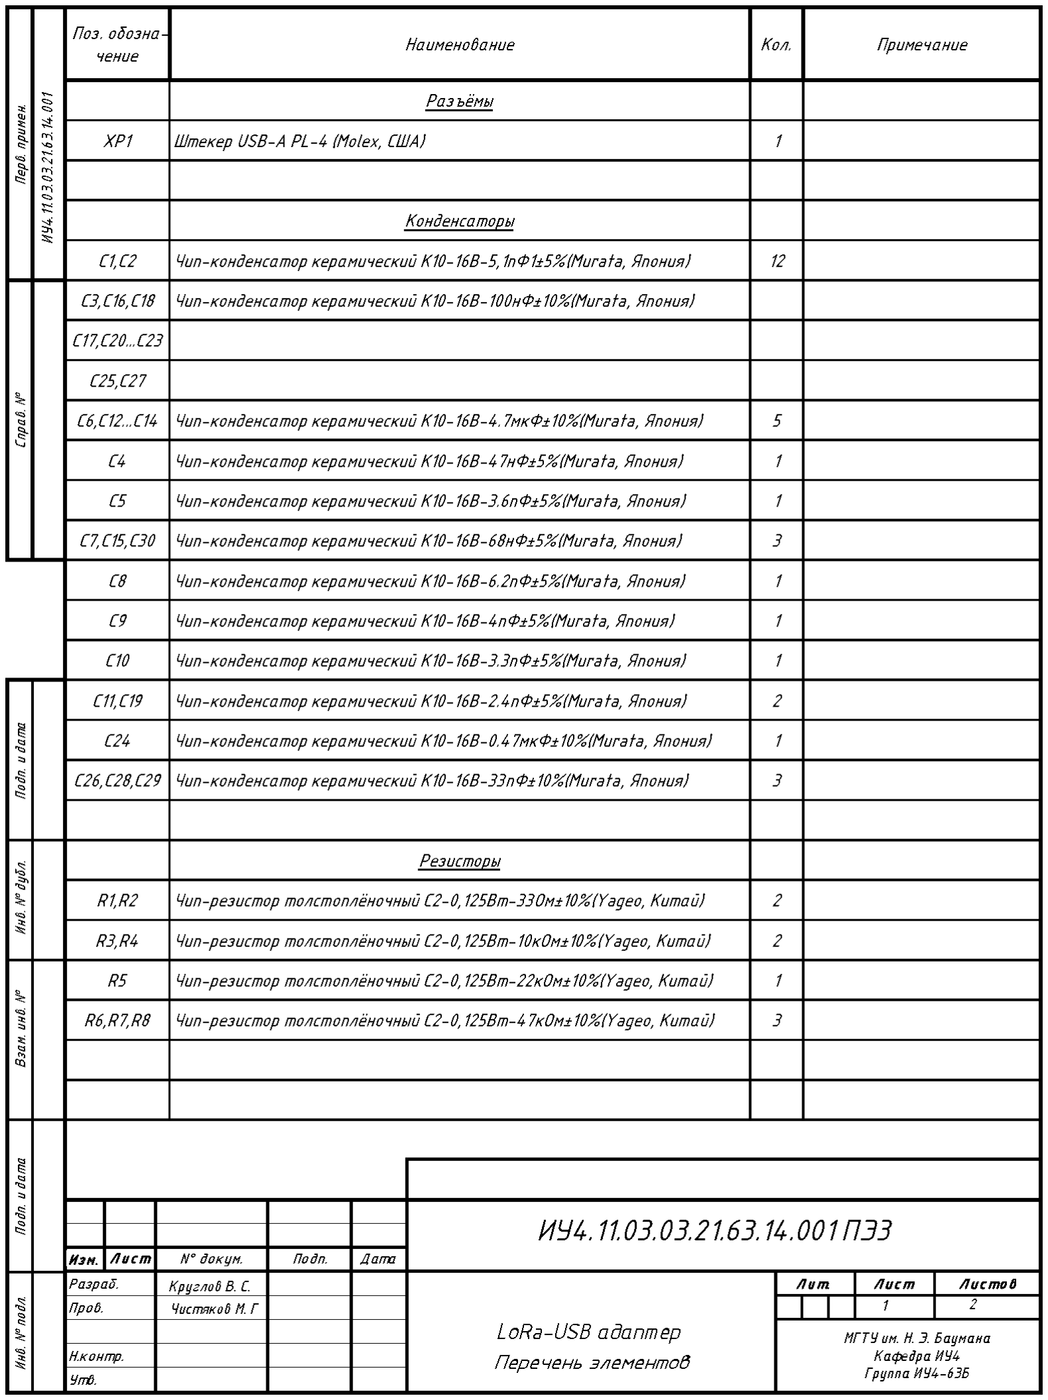
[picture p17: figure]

Рисунок 6.4.1 – Перечень элементов, первая страница

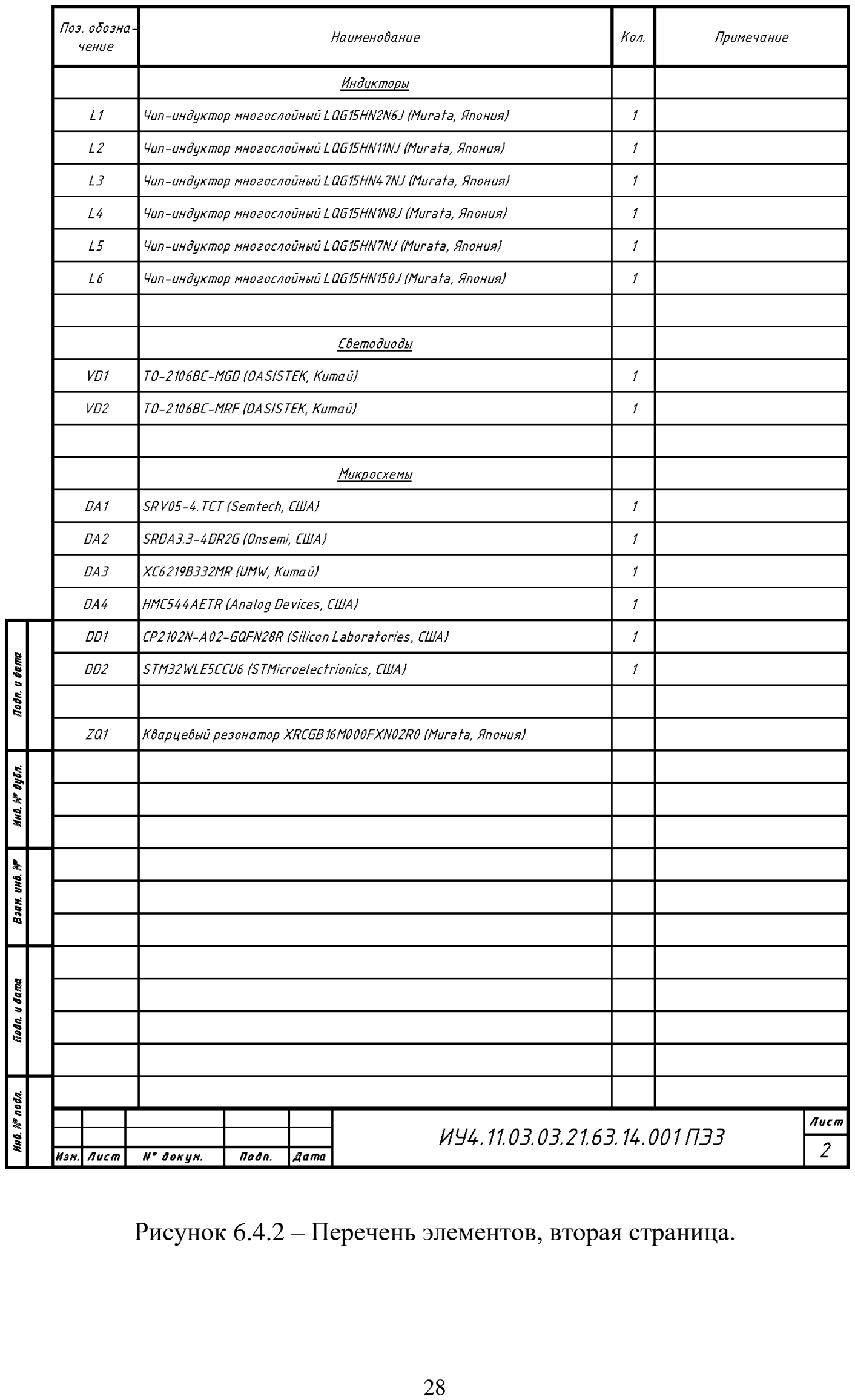
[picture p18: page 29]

Рисунок 6.4.2 – Перечень элементов, вторая страница.

Необходимые данные об элементах записываются в «Наименование» и

«Примечание». Туда указываются наименование в соответствии с документом,

на основании которого этот элемент (устройство) применен, - для

функциональной группы – наименование.

Связь перечня с УГО элементов осуществляется через графу «Поз.

Обозначения». Та, в свою очередь, в ПЭ3 проставляется на основе схемы

ИУ4.11.03.03.21.63.14.001 Э3.

Вывод

В | данном | разделе | была | разработана | схема | электрическая

принципиальная, при помощи программного пакета «Altium Designer».

Рассмотрен схемотехнический принцип работы устройства. Произведено

обоснование использования тех или иных элементов. Помимо этого, был

произведен расчет резистора для светодиода.

Таким образом результатом являются:

1. Чертеж схемы Электрической принципиальной Э3
2. Перечень элементов.

### 7 ПРОЕКТИРОВАНИЕ И ИЗГОТОВЛЕНИЕ ПЕЧАТНОЙ

ПЛАТЫ

### 7.1 Проектирование топологии печатной платы

Исходя из принципиальной схемы, представленной в п. 4.1 была

выполнена трассировка печатной платы и создана 3Д модель. В качестве среды

разработки был выбран САПР «Altium Designer 24», результат представлен на

рисунках 7.1.1.-7.1.4

Рисунок 7.1.1 – верхний внешний слой ПП

Рисунок 7.1.2 – верхний внутренний слой ПП

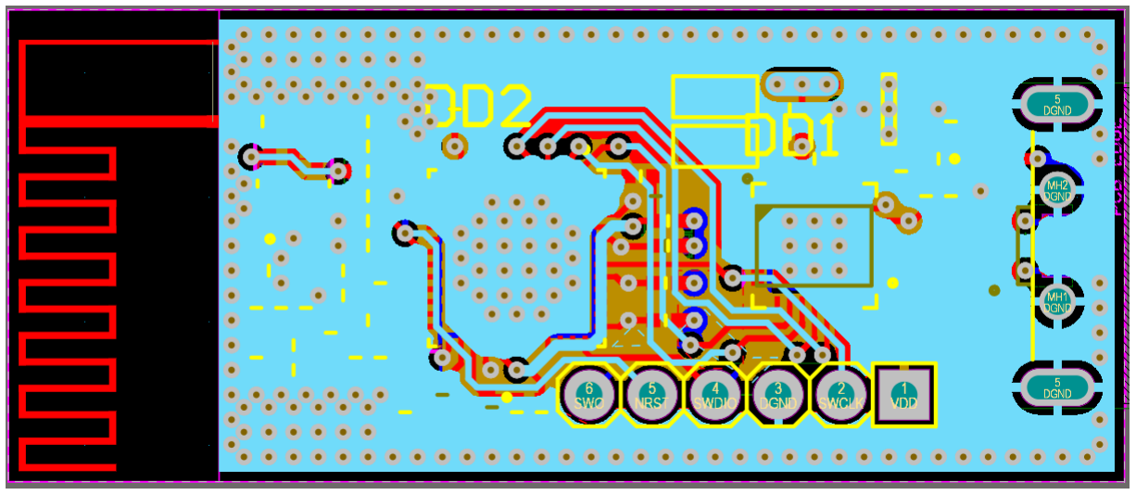
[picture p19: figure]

Рисунок 7.1.3 – нижний внутренний слой ПП

Рисунок 7.1.4 – нижний внешний слой ПП

При трассировке печатной платы основными целями были: компактность

изделия, простота изготовления и минимальная длина дорожек передачи данных.

Получилась двухсторонняя печатная плата габаритами 45х19 мм.

Толщина медных дороже варьируется от 0.2 до 0.52 мм, расстояние между

печатными проводниками печатной платы не менее 0.2 мм, что соответствует 4

классу точности.

В «Altium Designer 24» на основе посадочных мест была разработана 3Д

модель устройства, представленная на рисунке 7.1.5.

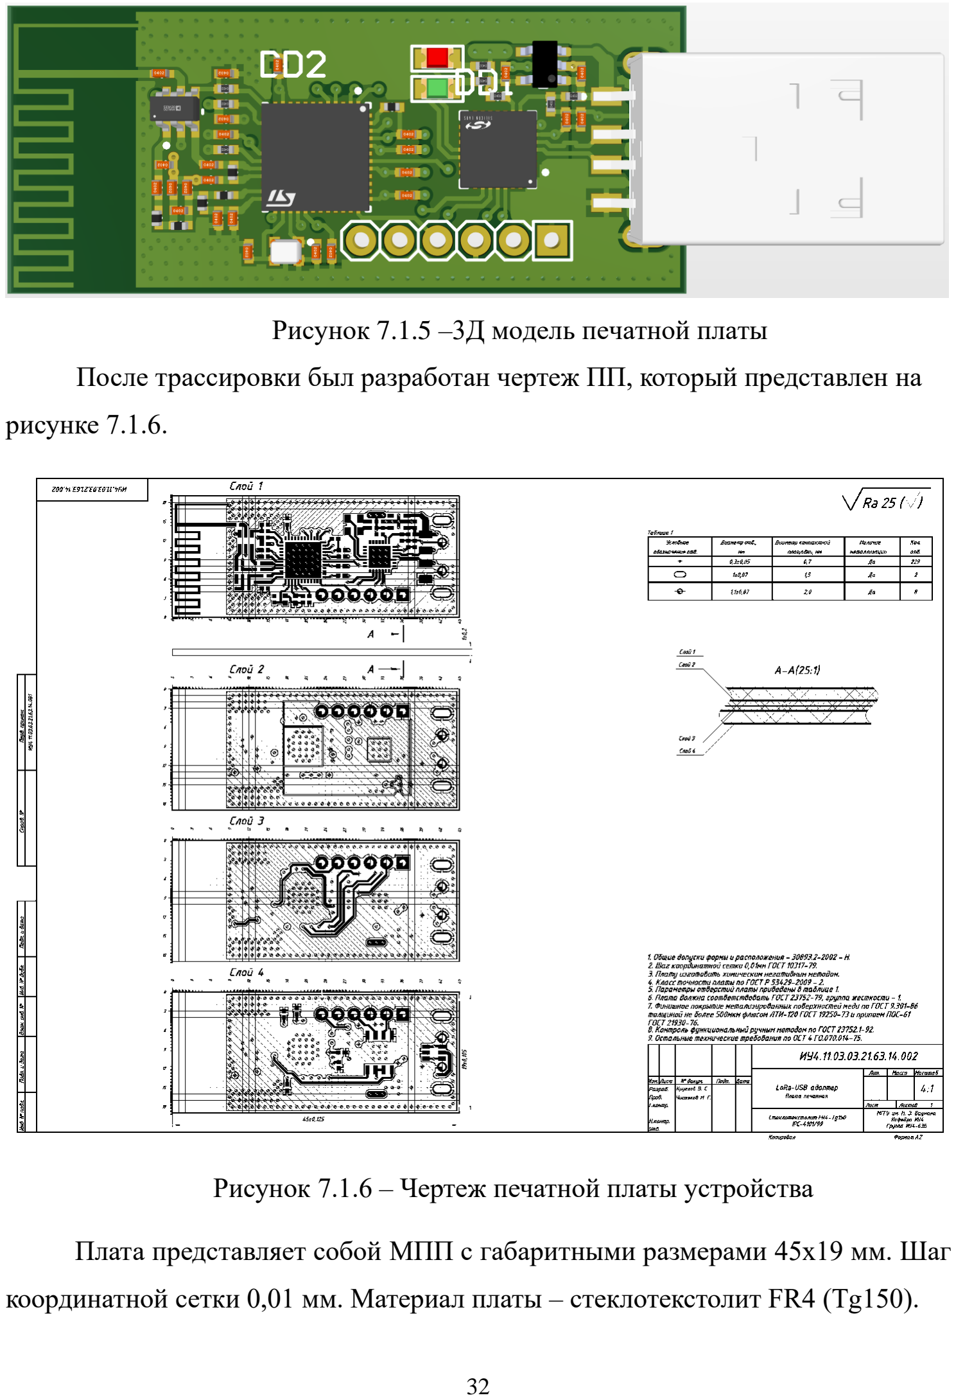
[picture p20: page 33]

Рисунок 7.1.5 –3Д модель печатной платы

После трассировки был разработан чертеж ПП, который представлен на

рисунке 7.1.6.

Рисунок 7.1.6 – Чертеж печатной платы устройства

Плата представляет собой МПП с габаритными размерами 45x19 мм. Шаг

координатной сетки 0,01 мм. Материал платы – стеклотекстолит FR4 (Tg150).

### 7.2 Изготовление печатной платы

Для изготовления двухсторонней печатной платы 4-го класса точности

было принято решение заказать производство платы на предприятии «PCB

Manufacture», так как в домашних условиях сложно получить металлизацию

отверстий и нужную степень точности.

Так как плата изготавливалась на специализированном предприятии,

была достигнута нужная степень точности.

Внешний вид печатной власти представлен на рис 7.2

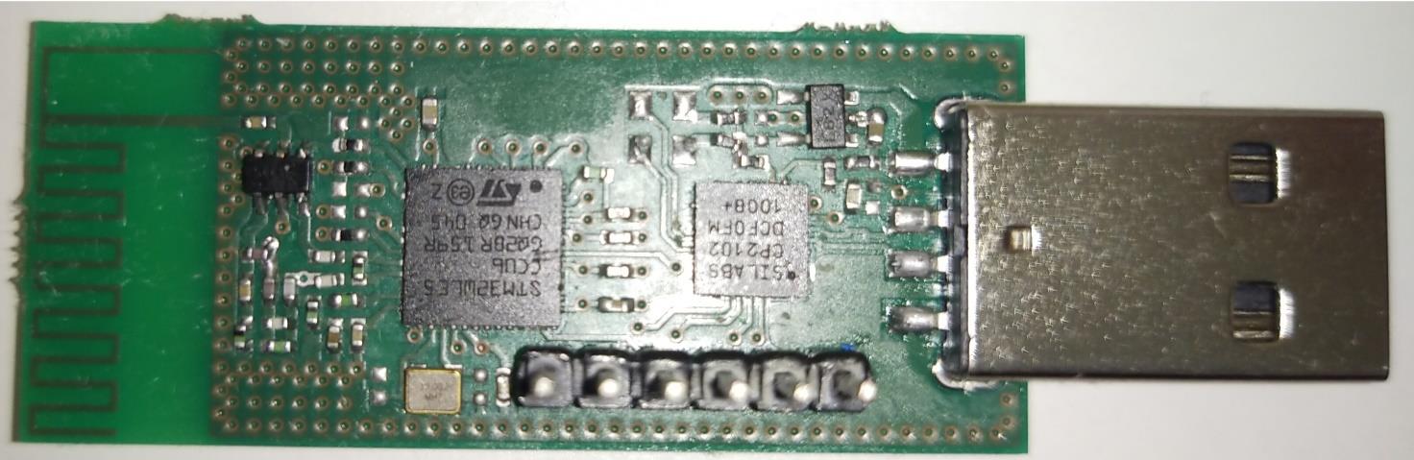
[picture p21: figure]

Рисунок 7.2 – Печатная плата устройства

Часть конденсаторов на входах питания не установлена для уменьшения

для уменьшения времени пайки, работа цифровых схем проверена и корректна.

Вывод

В данном разделе была произведена разработка топологии печатной

платы в соответствии с принципиальной схемой, указанной на рис 4.1. Так же

было обосновано то или иное технологическое решение при разработке

топологии печатной платы. Было приведено описание технологических и

схемотехнических решений, прямым образом влияющих на работу устройства,

таких как расстояние от помех генерирующих выводов до фильтрующих

конденсаторов, необходимость в малой длине сигнальных проводников.

Также в соответствии с разработанной топологией печатной платы был

изготовлен шаблон. Были объяснены способы и технология изготовления

шаблона для печатных плат, класс точности которых выше или равняется третьему. Так же была изготовлена сама печатная плата на предприятии «PCB

Manufacture».

Результатом данного раздела являются:

− Gerber-файлы отверстий и проводящего рисунка

− Фотошаблон проводящего рисунка верхнего слоя печатной платы

− Фотошаблон проводящего рисунка нижнего слоя печатной платы

− Прототип печатной платы, изготовленный методом фрезерования на

предприятии «PCB Manufacture»

### 8 РАЗРАБОТКА СБОРОЧНОГО ЧЕРТЕЖА И

СПЕЦИФИКАЦИИ УСТРОЙСТВА “LORA-USB АДАПТЕР”

### 8.1 Анализ сборочного состава

На основе топологии печатной платы, разработанной в п. 6 был

разработан сборочный чертеж печатной платы. На нем указана информация,

необходимая для сборки платы. На рисунке 8.1.1 представлена часть сборочного

чертежа, где показано расположение всех элементов на устройстве, а также их

обозначение в соответствии с принципиальной схемой (рисунок 4.1). Печатные

проводники условно не показаны. Неуказанные предельные отклонения

размеров ±IT12/2. Электромонтаж ИЭТ осуществляется согласно схеме

ИУ4.11.03.03.21.63.14.001 Э3.

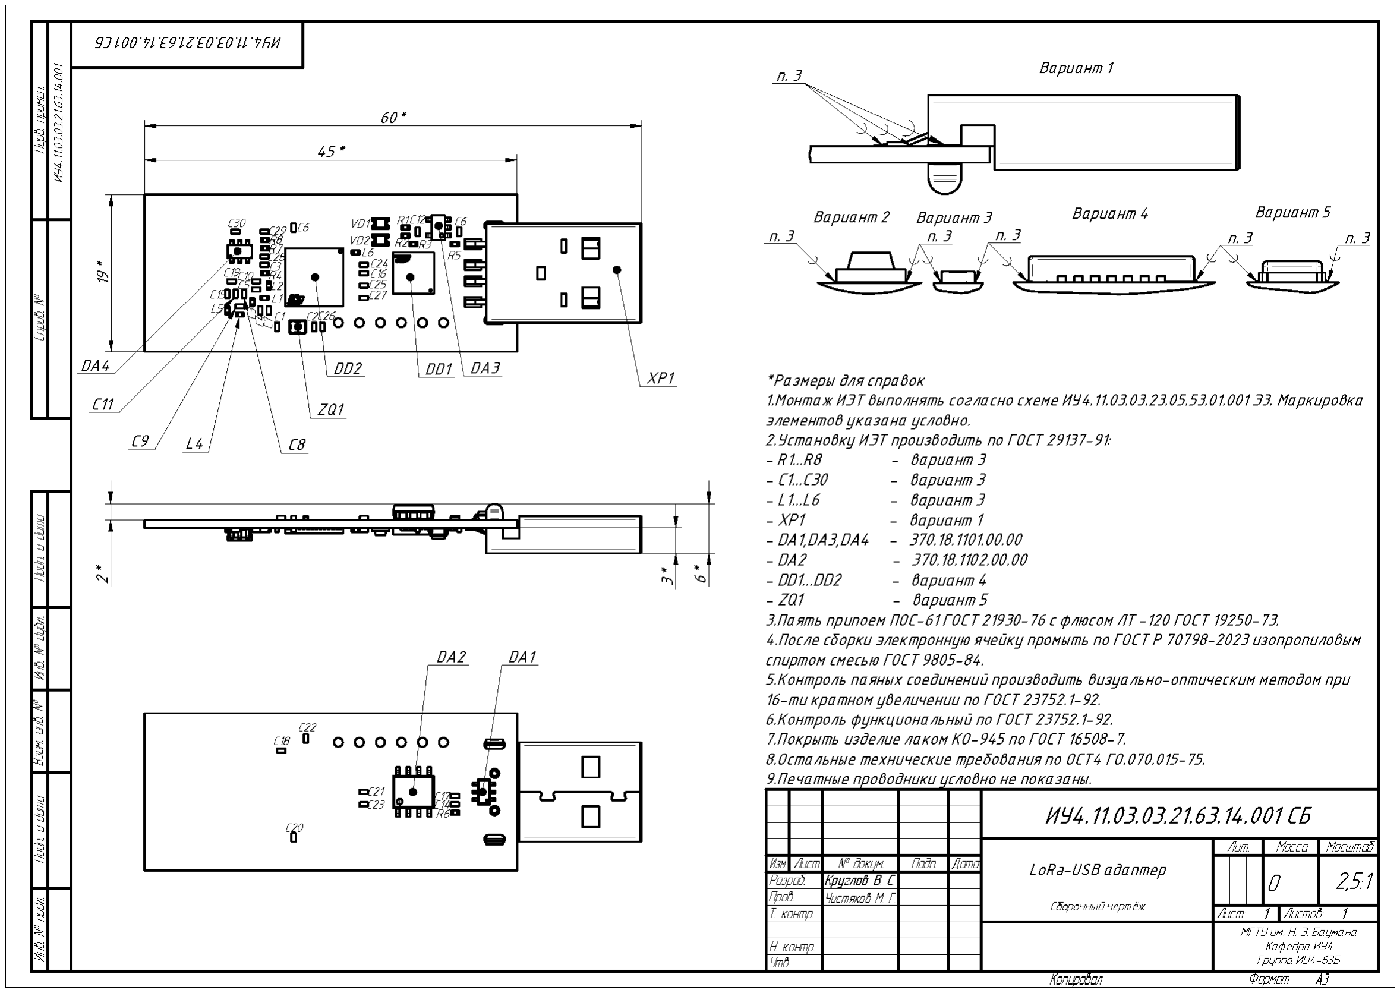
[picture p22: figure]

Рисунок 8.1.1 – Часть сборочного чертежа печатной платы

Габаритные размеры всего изделия составляют 45х68 мм. Пайку выводов

стоит производить ПОС-61 ГОСТ 21930-70 согласно ГОСТ 23592-96.

Допускается | применение | импортного | припоя | с | аналогичными

характеристиками.

Пайку устройства стоит проводить в следующем порядке:

1. Конденсаторы.
2. Резисторы.
3. Индукторы.
4. Микросхемы.
5. Разъемы.
6. Светодиоды.
7. Кварцевый резонатор.

После сборки устройство промыть в ультразвуковой очистительной ванне

со спирто-бензиновой смесью ГОСТ 18300-87.

Контроль | паянных | соединений | проводить | визуально-оптическим

методом по ГОСТ 24715-81.

Остальные технические требования по ОСТ 4 Г0.070.14-75.

### 8.2 Разработка спецификации

Спецификация – основной документ курсовой работы. В спецификацию

вносят составные части, входящие в специфицируемое изделие, а также

конструкторские документы, относящиеся к этому изделию и к его

неспецифицируемым составным частям.

Страницы СП представлены на рисунках 8.2.1, 8.2.2 и непосредственно в

самом документе спецификации ИУ4.11.03.03.21.63.14.001.

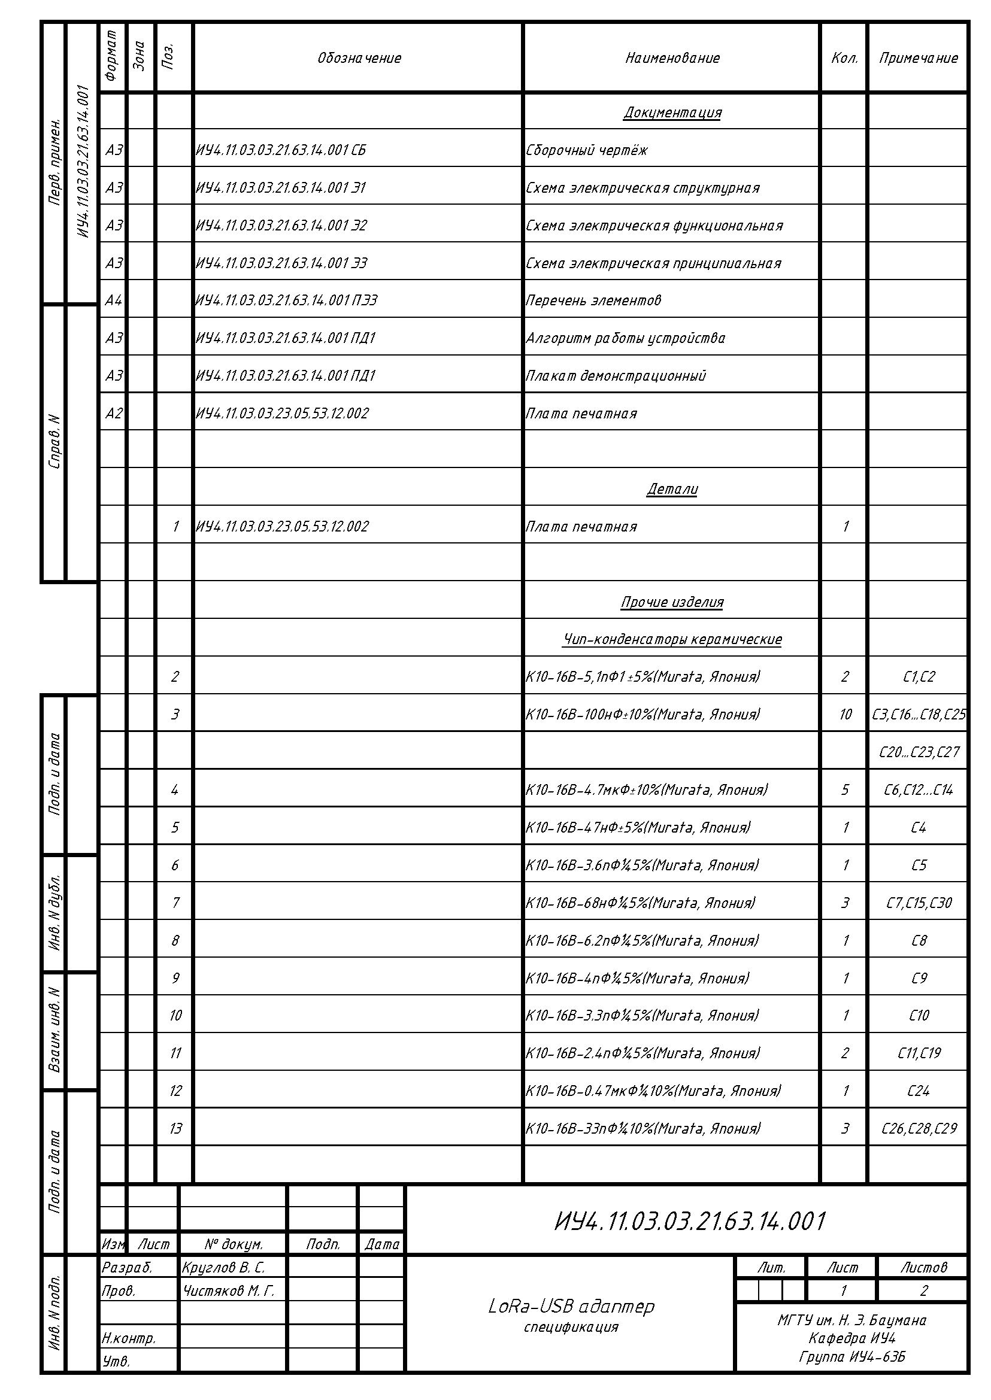
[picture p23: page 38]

Рисунок 8.2.1 –Первая страницы спецификации устройства

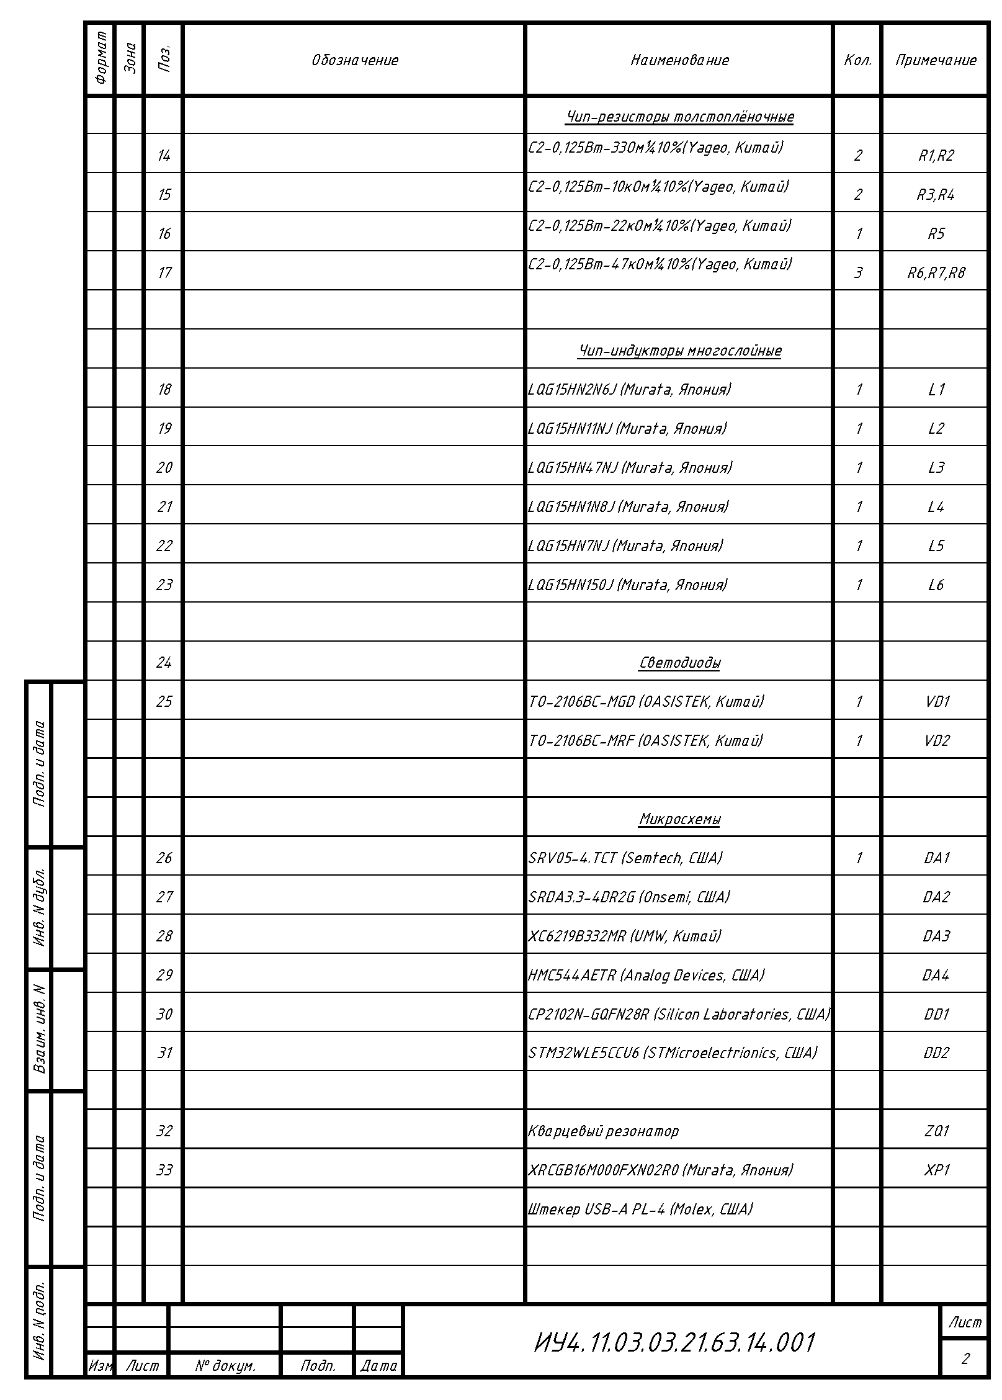
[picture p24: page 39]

Рисунок 8.2.2 – Вторая страницы спецификации устройства

СП устройства LoRa-USB адаптера разработана в соответствии с ГОСТ

2.106 и состоит из следующих разделов в соответствующей последовательности:

− Документация.

− Детали.

− Прочие изделия.

В раздел «Документация» внесены все документы, составляющие

основной комплект конструкторских документов специфицируемого изделия,

кроме самой спецификации, а также документы основного комплекта

записываемых в спецификацию неспецифицируемых составных частей

(деталей), кроме их рабочих чертежей.

В раздел «Детали» была внесена деталь, непосредственно входящая в

специфицируемое изделие – плата печатная.

Раздел «Прочие изделия» схож по наполнению с перечнем элементов

(ПЭ3), за исключением того, что запись изделий в пределах каждой группы

происходит в алфавитном порядке наименований изделий, а обозначения УГО

элементов записываются в графу «Примечание».

Вывод

В данном разделе был разработан технологический маршрут сборки

устройства. Был разработан сборочный чертеж, в соответствии с которым

должна производиться сборка прототипа устройства. Была указана методика

осуществления контроля паяных соединений.

Таким образом, результатом разделается является пакет конструкторской

документации на сборку макета устройства, в который входят:

− Сборочный чертеж устройства.

− Спецификация.

### 9 РАЗРАБОТКА ПРОГРАММНОГО ОБЕСПЕЧЕНИЯ “LORA-

USB АДАПТЕР”

Для данного устройства был разработан алгоритм работы (ПД1) на основе

прерываний. Устройство ожидает получения передаваемых данных по UART,

после чего или немедленно их отправляет, или ожидает события окончания

передачи.

Разработанный алгоритм представлен на рисунке 9.1 и на чертеже

ИУ4.11.03.03.21.63.14.001 ПД1.

Рисунок 9.1 – Алгоритм работы программного обеспечения устройства

Программное обеспечение было разработано в среде разработки

STM32CubeIDE с помощью библиотеки HAL.

Настройки выводов микроконтроллера представлены на рисунке 9.2.


Рисунок 9.2 – Конфигурация выводов микроконтроллера

Вывод

В данном разделе был разработан алгоритм работы программного

обеспечения, который позволяет осуществлять обработку данных. Данный

алгоритм является оптимальный с точки зрения потребления памяти и скорости

работы.

### 10 ЭКСПЕРИМЕНТАЛЬНОЕ ИССЛЕДОВАНИЕ УСТРОЙСТВА

Целью данного раздела является экспериментальное исследование

устройства для выявления некорректного поведения программной или

аппаратной части.

Исследование производилось в соответствии с разработанной схемой

измерительного стенда (ПД2). Схема представления на рисунке 9.1 и на чертеже

ИУ4.11.03.03.21.63.14.001 ПД1.

Было проведено исследование работы аналоговой части устройства, а

именно цепей спектрограммы эфира во время передачи данных. Исследование

проводилось в соответствии с разработанной схемой измерительного стенда,

представленной на рисунке 10.1.


Рисунок 10.1 – Сравнение моделирование и эксперимента

Измерения были проведены с помощью SDR в режиме непрерывного

сканирования эфира. Выполнено сравнение получившихся значений с

результатами моделирования данной цепи. Значения частот передачи совпадают,

выведенные в терминал сообщения совпадают.

Вывод

В результате данного раздела было подтверждено корректное

функционирование алгоритма и правильность работы цепей с транзисторами и,

как следствие, всего устройства в целом. По результатам данного тестирования

можно сделать вывод что устройство удовлетворяет требованиям ТЗ, с точки

зрения корректности и качества работы.

ЗАКЛЮЧЕНИЕ

В ходе курсового проекта спроектировано, разработано, собрано и

протестировано устройство «LoRa-USB адаптер», полностью удовлетворяющее

выданному ТЗ. Разработана схема электрическая структурная (Э1), схема

электрическая функциональная (Э2), на основе этих схема разработана

электрическая принципиальная схема (Э3).

Также было проведено моделирование устройство, по результатам

которого было подтверждено корректное функционирование устройства.

Представлена принципиальная схема работы устройства, представлено

обоснование выбора элементной базы устройства и составлен перечень

элементов (ПЭ3).

Произведено проектирование печатной платы и ее изготовление в

соответствии с принципиальной схемой и схемой трассировки. Представлен

чертеж печатной платы. Была разработана спецификация и сборочный чертеж

устройства, а также технологический маршрут его сборки.

Полученное в ходе разработки устройство способно корректно выполнять

функции в соответствии с полученными через USB данными. Также стоит

отметить положительные качества устройства, такие как компактность и

простота управления. Благодаря использованию современной компонентной

базы и оптимизации схемотехнических решений, устройство компактно по

размеру и имеет низкое энергопотребление, что делает его удобным в

использовании и транспортировки. Интерфейс устройства «LoRa-USB адаптер»

разработан таким образом, что управление интуитивно понятно.

Из отрицательных качеств можно выделить малую мощность передачи

вследствие малых габаритов антенны и сложность пайки малых компонентов.

Разработанное устройство может быть использовано в качестве средства

коммуникации или в образовательных целях для изучения и отладки LoRa-WAN

сетей. Задание на курсовую работу считаю выполненным в полном объеме.

СПИСОК ИСПОЛЬЗОВАННЫХ ИСТОЧНИКОВ

[1] М. Х. Джонс. Электроника – практический курс. Москва: Постмаркет,1999. –

528с.

[2] ГОСТ 2.701-2008 Единая система конструкторской документации (ЕСКД).

Схемы. Виды и типы. Общие требования к выполнению (с поправкой).

[3] ГОСТ 2.702-2011 Единая система конструкторской документации (ЕСКД).

Правила выполнения электрических схем.

[4] Монк, Саймон. Электроника. Теория и практика – 4-е изд.: Пер. с англ./

Саймон Монк, Пауль Шерц. – СПб.: БХВ-Петербург, 2018. – 1168 с.:ил. –

(Электроника)

[5] Хоровиц П., Хилл У. Искусство схемотехники: Пер. с англ. – 5-е изд, перераб

_ М.: Мир, 1998. – 704 с., ил.

[6] Семенцов С.Г., сборник лекции по курсу “Основы аналого-цифровой

схемотехники”.

[7] ГОСТ 23752-79 Платы печатные. Общие технические условия (С

изменениями №1-5).

[8] ГОСТ Р 53429-2009 Платы печатные. Основные параметры конструкции.
[9] ГОСТ 10316-78 Гетинакс и стеклотекстолит фольгированные. Технические

условия (с Изменениями №1-6).

[10] ГОСТ 21930-76 Припои оловянно-свинцовые в чушках. Технические

условия (с Изменениями №1,2,3,4).

[11] ГОСТ 11284-75 Отверстия сквозные под крепежные детали. Размеры (С

изменением №1)

[12] ГОСТ 29137-91 Формовка выводов и установка изделий электронной

техники на печатные платы. Общие требования и нормы конструирования.

[13] ГОСТ 23592-96 Монтаж электрический радиоэлектронной аппаратуры и

приборов. Общие требования к объемному монтажу изделий электронной

техники и электротехнических.

[14] ГОСТ 18300-87 Спирт этиловый ректификованный технический.

Технические условия.

[15] ГОСТ 24715-81 Соединения паяные. Методы контроля качества.
[16] ГОСТ 2.106 Единая система конструкторской документации (ЕСКД).

Текстовые документы (с Изменением №1).

[17] Проектирование коммутационных структур электронных средств: учеб.

пособие / В.Н. Гриднев, Г. Н. Гриднева – М.: Изд-во МГТУ им. Н.Э.Баумана,

2014 – 344 с.: ил. (Библиотека “Конструирование и технология электронных

средств” в 25 кн. Кн.7).

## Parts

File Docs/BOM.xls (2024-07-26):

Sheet: Главный
Разработал: Круглов В. С. | Круглов В. С. | Тип печатной платы необходим для добавления номера документа печатной платы в спецификаию:
Проверил: Чистяков М. Г. | Field=CheckedBy | 1 - сборочная единица
Норм. контроль: | Field=N_kontr | 2 - деталь
Утвердил: | Field=ApprovedBy
Литера: | Field=lit_A | Параметр GroupSpecification служит для помещения компонента в один из разделов:
Децимальный нормер: | Field=DecimalNumber | 1 - Сборочные единицы
Наименование проекта: | Field=Name1 | 2 - Детали
 | Field=Name2 | 3 - Стандартные изделия
Организация: МГТУ им. Н. Э. Баумана | Field=CompanyName | 4 - Прочие изделия (раздел по умолчанию)
Дец. номер документа печатной платы: | Field=PcbNumber | Если компонент не относится к разделу "Прочие изделия" то в параметре Rem указывается наименование позции, а в параметре
Тип печ. платы (сборка/деталь): | Field=PcbType | DocNumber - децимальный номер чертежа
Column=Designator | Column=Rem | Column=Корпус | Column=Value | Column=Tolerance | Column=Power/Voltage | Column=Type | Column=ManufacturerPartNumber | Column=Manufacturer | Column=Quantity | Column=Примечание | Column=GroupSpecification | Column=DocNumber
1 | 2 | 3 | 4 | 5 | 6 | 7 | 8 | 9 | 10 | 11 | 12 | 13

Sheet: Компоненты
Поз. обозначение | Наименование ед.ч. | Наименование мн.ч.
A | Устройство | Устройства
BAT | Элемент питания | Элементы питания
BF | Телефон | Телефоны
BH | Датчик Холла | Датчики Холла
BM | Микрофон | Микрофоны
C | Конденсатор | Конденсаторы
D | Микросхема | Микросхемы
DA | Микросхема | Микросхемы
DD | Микросхема | Микросхемы
FU | Предохранитель | Предохранители
F | Разрядник | Разрядники
GB | Батарея | Батареи
G | Генератор | Генераторы
H | Устройство индикации | Устройства индикации
HG | Устройство индикации | Устройства индикации
HL | Устройство индикации | Устройства индикации
K | Реле | Реле
KV | Реле | Реле
L | Катушка индуктивности | Катушки индуктивности
R | Резистор | Резисторы
RK | Терморезистор | Терморезисторы
RP | Потенциометр | Потенциометры
RU | Варистор | Варисторы
S | Переключатель | Переключатели
SA | Переключатель | Переключатели
SB | Переключатель | Переключатели
T | Трансформатор | Трансформаторы
VD | Диод | Диоды
VS | Тиристор | Тиристоры
VT | Транзистор | Транзисторы
WA | Антенна | Антенны
X | Соединитель | Соединители
XP | Соединитель | Соединители
XS | Соединитель | Соединители
XW | Соединитель | Соединители
Z | Кварцевый резонатор | Кварцевые резонаторы
ZQ | Кварцевый резонатор | Кварцевые резонаторы
FP | Термопредохранитель | Термопредохранители
U | Оптопара | Оптопары

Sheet: Сп 1
Перв. примен. | Формат | Зона | Поз. | Обозначение | Наименование | Кол. | Примечание
Справ. №
Подп. и дата
Инв. № дубл.
Взам. инв. №
Подп. и дата
Инв. № подл.

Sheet: Сп 2
 | Формат | Зона | Поз. | Обозначение | Наименование | Кол. | Примечание
Подп. и дата
Инв. № дубл.
Взам. инв. №
Подп. и дата
Инв. № подл.

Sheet: Лист 1
Перв. примен. | Поз. обозна-чение | Наименование | Кол. | Примечание
 |  | Разъёмы
 | XP1 | Штекер USB-A PL-4 (Molex, США) | 1
 |  | Конденсаторы
 | С1,C2 | Чип-конденсатор керамический К10-16В-5,1пФ1±5%(Murata, Япония) | 12
Справ. № | C3,C16,C18 | Чип-конденсатор керамический К10-16В-100нФ±10%(Murata, Япония)
 | C17,C20…C23
 | C25,C27
 | C6,C12...C14 | Чип-конденсатор керамический К10-16В-4.7мкФ±10%(Murata, Япония) | 5
 | C4 | Чип-конденсатор керамический К10-16В-47нФ±5%(Murata, Япония) | 1
 | C5 | Чип-конденсатор керамический К10-16В-3.6пФ±5%(Murata, Япония) | 1
 | C7,C15,C30 | Чип-конденсатор керамический К10-16В-68нФ±5%(Murata, Япония) | 3
 | C8 | Чип-конденсатор керамический К10-16В-6.2пФ±5%(Murata, Япония) | 1
 | С9 | Чип-конденсатор керамический К10-16В-4пФ±5%(Murata, Япония) | 1
 | С10 | Чип-конденсатор керамический К10-16В-3.3пФ±5%(Murata, Япония) | 1
Подп. и дата | С11,C19 | Чип-конденсатор керамический К10-16В-2.4пФ±5%(Murata, Япония) | 2
 | C24 | Чип-конденсатор керамический К10-16В-0.47мкФ±10%(Murata, Япония) | 1
 | C26,C28,C29 | Чип-конденсатор керамический К10-16В-33пФ±10%(Murata, Япония) | 3
Инв. № дубл. |  | Резисторы
 | R1,R2 | Чип-резистор толстоплёночный C2-0,125Вт-33Ом±10%(Yageo, Китай) | 2
 | R3,R4 | Чип-резистор толстоплёночный C2-0,125Вт-10кОм±10%(Yageo, Китай) | 2
Взам. инв. № | R5 | Чип-резистор толстоплёночный C2-0,125Вт-22кОм±10%(Yageo, Китай) | 1
 | R6,R7,R8 | Чип-резистор толстоплёночный C2-0,125Вт-47кОм±10%(Yageo, Китай) | 3
Подп. и дата
Инв. № подл.

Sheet: Лист 2
 | Поз. обозна-чение | Наименование | Кол. | Примечание
 |  | Индукторы
 | L1 | Чип-индуктор многослойный LQG15HN2N6J (Murata, Япония) | 1
 | L2 | Чип-индуктор многослойный LQG15HN11NJ (Murata, Япония) | 1
 | L3 | Чип-индуктор многослойный LQG15HN47NJ (Murata, Япония) | 1
 | L4 | Чип-индуктор многослойный LQG15HN1N8J (Murata, Япония) | 1
 | L5 | Чип-индуктор многослойный LQG15HN7NJ (Murata, Япония) | 1
 | L6 | Чип-индуктор многослойный LQG15HN150J (Murata, Япония) | 1
 |  | Светодиоды
 | VD1 | TO-2106BC-MGD (OASISTEK, Китай) | 1
 | VD2 | TO-2106BC-MRF (OASISTEK, Китай) | 1
 |  | Микросхемы
 | DA1 | SRV05-4.TCT (Semtech, США) | 1
 | DA2 | SRDA3.3-4DR2G (Onsemi, США) | 1
 | DA3 | XC6219B332MR (UMW, Китай) | 1
 | DA4 | HMC544AETR (Analog Devices, США) | 1
Подп. и дата | DD1 | CP2102N-A02-GQFN28R (Silicon Laboratories, США) | 1
 | DD2 | STM32WLE5CCU6 (STMicroelectrionics, США) | 1
 | ZQ1 | Кварцевый резонатор XRCGB16M000FXN02R0 (Murata, Япония)
Инв. № дубл.
Взам. инв. №
Подп. и дата
Инв. № подл.

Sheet: Рег. Изм.
 | ЛИСТ РЕГИСТРАЦИИ ИЗМЕНЕНИЙ
 | Изм. | Номера листов (страниц) |  |  |  | Всего листов (страниц) в докум. | № докум. | Входящий № сопроводитель- ного докум. и дата | Подпись | Дата
 |  | изменен- ных | заменен- ных | новых | аннули- рованных
Подп. и дата
Инв. № дубл.
Взам. инв. №
Подп. и дата
Инв. № подл.

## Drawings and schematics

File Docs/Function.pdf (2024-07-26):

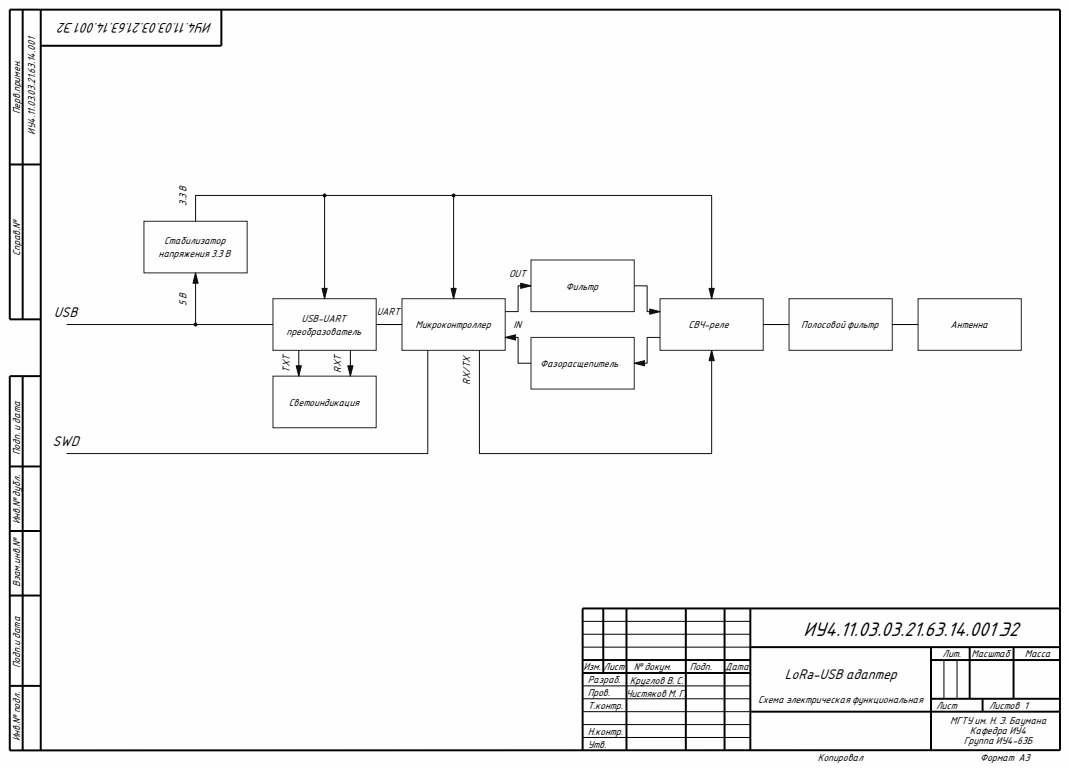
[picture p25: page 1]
Копировал; USB-UART; Стабилизатор; Светоиндикация; Микроконтроллер; СВЧ-реле; Полосовой фильтр; Антенна; напряжения 3.3 В; преобразователь; USB; SWD; Фазорасщепитель; Фильтр 5 В 3.3 В; TXT; RXT; UART; OUT

Формат A3 Справ.№ Перв.примен.

Инв.№ подл. Подп.и дата Взам.инв.№ Инв.№ дубл. Подп. и дата

LoRa-USB адаптер Схема электрическая функциональная | Лит. | Масштаб | Масса

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

МГТУ им. Н. Э. Баумана Кафедра ИУ4 Группа ИУ4-63Б

Н.контр.
Утв.

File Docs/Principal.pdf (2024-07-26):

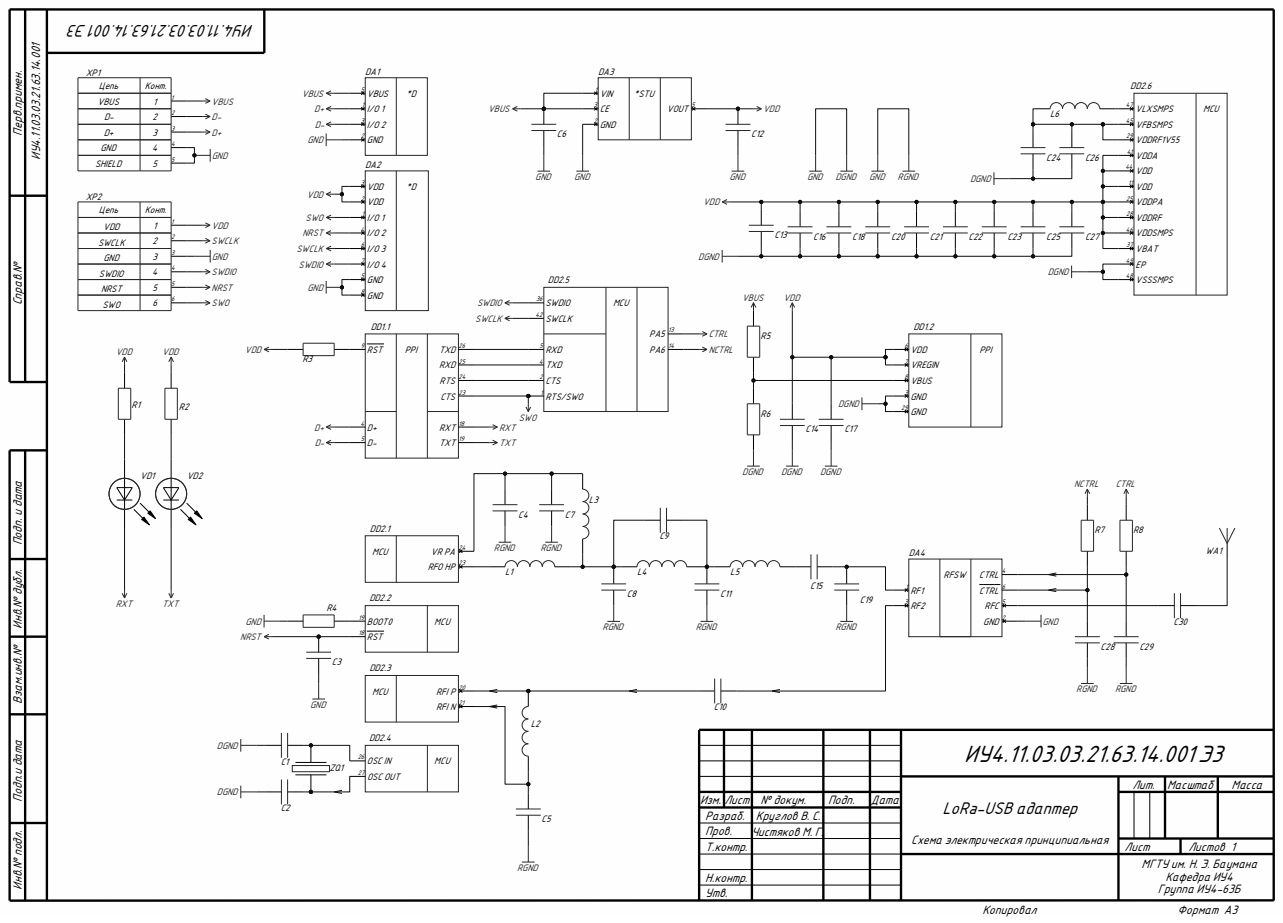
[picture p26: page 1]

Формат A3 Справ.№ Перв.примен.

Цепь | Конт.
VBUS | 1

GND DGND GND RGND

NRST | 5
SWO | 6

Инв.№ подл. Подп.и дата Взам.инв.№ Инв.№ дубл. Подп. и дата

LoRa-USB адаптер Схема электрическая принципиальная | Лит. | Масштаб | Масса

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

МГТУ им. Н. Э. Баумана Кафедра ИУ4 Группа ИУ4-63Б

Н.контр.
Утв.

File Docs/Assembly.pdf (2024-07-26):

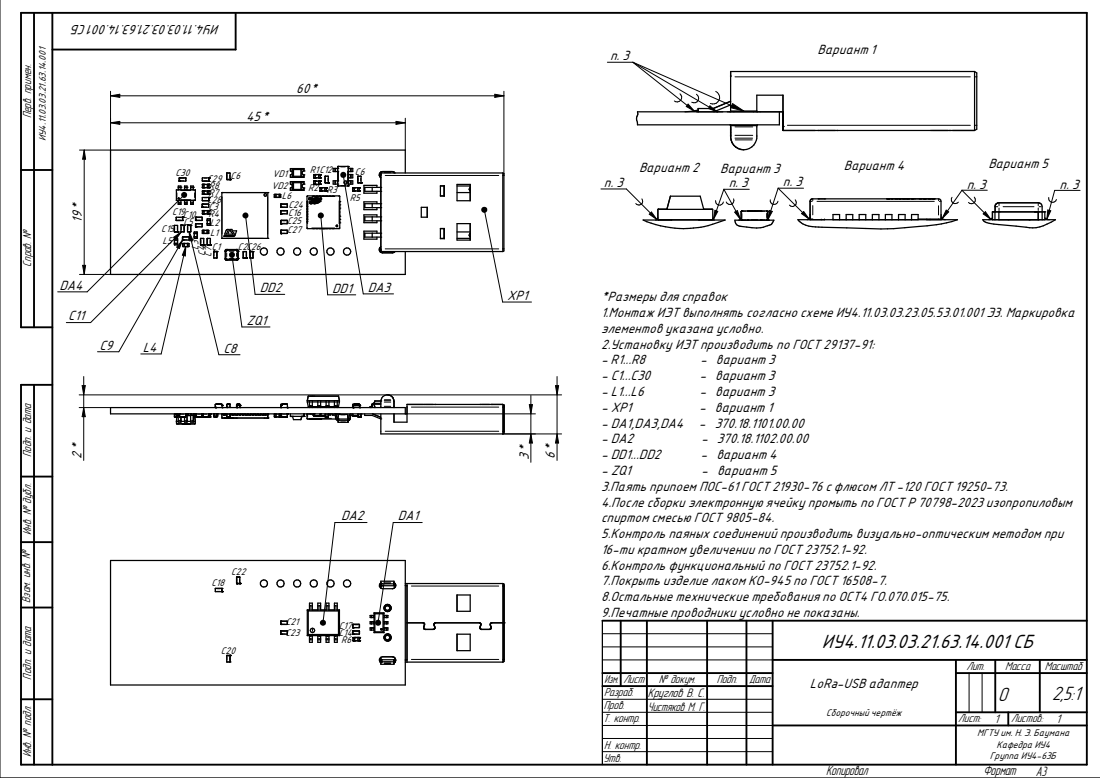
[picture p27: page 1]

Инв. № подл. Подп. и дата Взам. инв. № Инв. № дубл. Подп. и дата Справ. № Перв. примен.

*Размеры для справок
1.Монтаж ИЭТ выполнять согласно схеме ИУ4.11.03.03.23.05.53.01.001 Э3. Маркировка
элементов указана условно.
2.Установку ИЭТ производить по ГОСТ 29137-91:
3.Паять припоем ПОС-61 ГОСТ 21930-76 с флюсом ЛТ -120 ГОСТ 19250-73.
4.После сборки электронную ячейку промыть по ГОСТ Р 70798-2023 изопропиловым
спиртом смесью ГОСТ 9805-84.
5.Контроль паяных соединений производить визуально-оптическим методом при
16-ти кратном увеличении по ГОСТ 23752.1-92.
6.Контроль функциональный по ГОСТ 23752.1-92.
7.Покрыть изделие лаком КО-945 по ГОСТ 16508-7.
8.Остальные технические требования по ОСТ4 ГО.070.015-75.
9.Печатные проводники условно не показаны.

LoRa-USB адаптер Сборочный чертёж | Лит. | Масса | Масштаб

Изм. Лист | № докум. | Подп. | Дата | | | | | 0 2,5:1
Разраб. | Круглов В. С.
Пров. | Чистяков М. Г.
Т. контр. | | | | Лист: 1 1 | Листов:

МГТУ им. Н. Э. Баумана Кафедра ИУ4 Группа ИУ4-63Б

Н. контр.
Утв.

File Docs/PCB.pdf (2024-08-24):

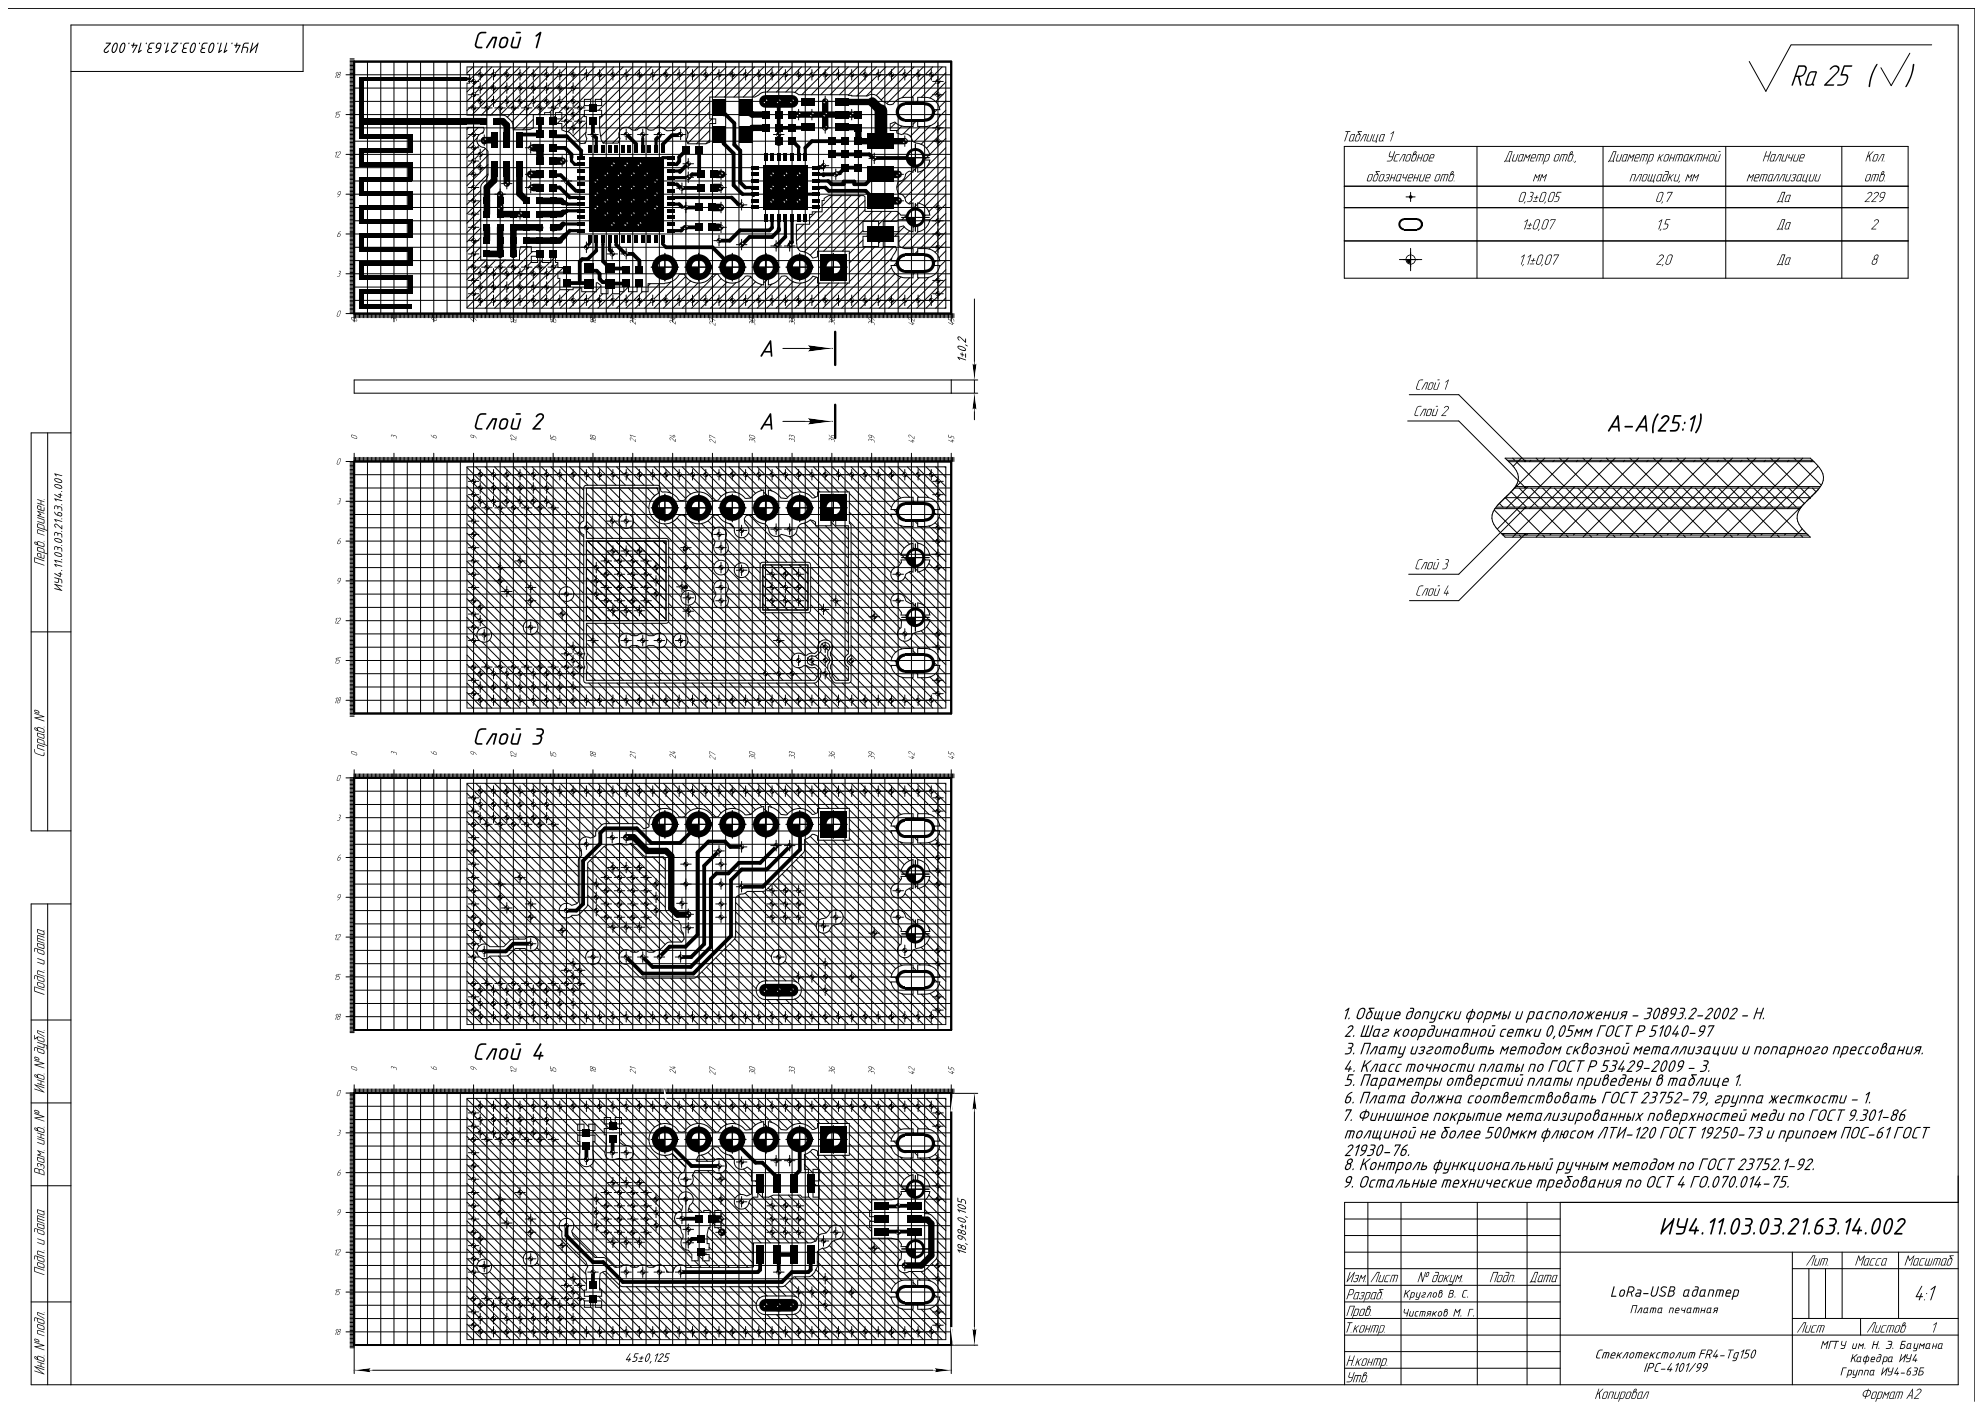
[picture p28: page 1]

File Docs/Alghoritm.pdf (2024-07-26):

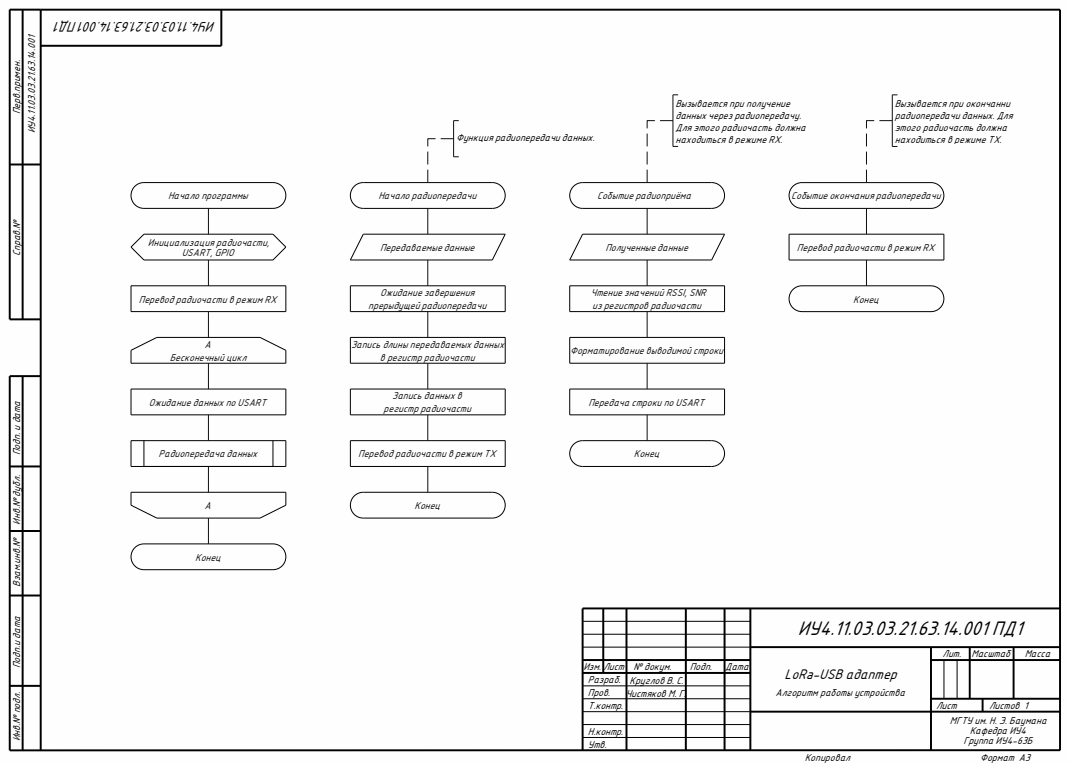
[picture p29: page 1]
Копировал; Начало программы; Начало радиопередачи; Конец; Инициализация радиочасти,; Радиопередача данных; Событие радиоприёма; Передаваемые данные; Запись данных в; USART, GPIO; Полученные данные; Ожидание завершения прерыдущей радиопередачи; Бесконечный цикл; регистр радиочасти

Формат A3 Справ.№ Перв.примен.

Вызывается при получение
данных через радиопередачу.
Для этого радиочасть должна
находиться в режиме RX.

Вызывается при окончанни
радиопередачи данных. Для
этого радиочасть должна
находиться в режиме TX.

Функция радиопередачи данных.

Событие окончания радиопередачи

Перевод радиочасти в режим RX

Чтение значений RSSI, SNR
из регистров радиочасти

Запись длины передаваемых данных
в регистр радиочасти

Форматирование выводимой строки

Инв.№ подл. Подп.и дата Взам.инв.№ Инв.№ дубл. Подп. и дата

Ожидание данных по USART

Передача строки по USART

Перевод радиочасти в режим TX

LoRa-USB адаптер Алгоритм работы устройства | Лит. | Масштаб | Масса

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

МГТУ им. Н. Э. Баумана Кафедра ИУ4 Группа ИУ4-63Б

Н.контр.
Утв.

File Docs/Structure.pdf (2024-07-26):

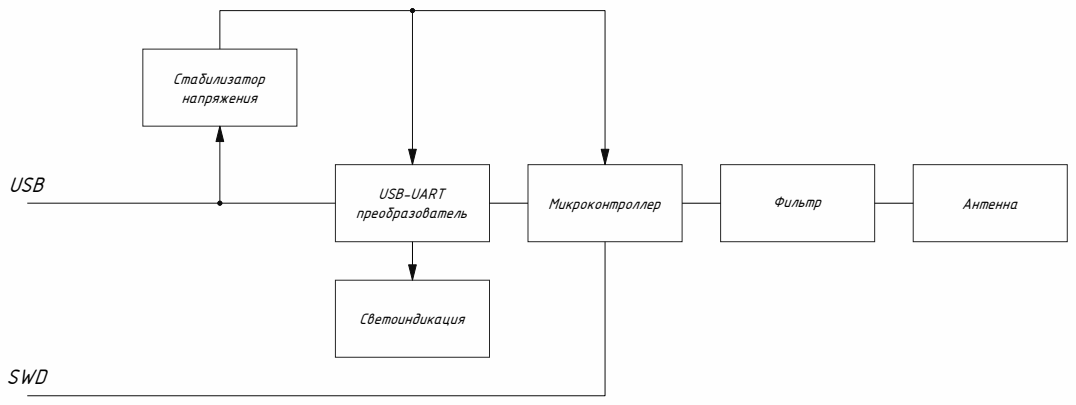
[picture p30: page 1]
Копировал; USB-UART; Стабилизатор; Светоиндикация; Микроконтроллер; Антенна; напряжения; преобразователь; USB; SWD; Фильтр

Формат A3 Справ.№ Перв.примен.

Инв.№ подл. Подп.и дата Взам.инв.№ Инв.№ дубл. Подп. и дата

LoRa-USB адаптер Схема электрическая структурная | Лит. | Масштаб | Масса

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

МГТУ им. Н. Э. Баумана Кафедра ИУ4 Группа ИУ4-63Б

Н.контр.
Утв.

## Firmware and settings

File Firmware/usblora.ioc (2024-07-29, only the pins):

Mcu.UserName=STM32WLE5CCUx
PA5.Signal=GPIO_Output
PA6.Signal=GPIO_Output
PB3.Signal=USART1_RTS
PB4.Signal=USART1_CTS
PB6.Signal=USART1_TX
PB7.Signal=USART1_RX

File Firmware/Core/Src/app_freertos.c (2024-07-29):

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

/* Includes ------------------------------------------------------------------*/
#include "FreeRTOS.h"
#include "task.h"
#include "main.h"
#include "cmsis_os.h"

#include "app_subghz_phy.h"

/* USER CODE BEGIN Includes */
#include "usart.h"
#include "string.h"
#include "stdlib.h"
#include "radio.h"
#include "stddef.h"
/* USER CODE END Includes */

/* USER CODE BEGIN Variables */
static RadioEvents_t RadioEvents;

#pragma region cli
uint8_t welcome[] =
    "\n\r"
    "|------------------------------------------------------------------------------|\n\r"
    "|  ╔╗╔╗╔══╗╔╗  ╔═══╗╔╗ ╔╗╔══╗╔╗╔══╗╔╗╔══╗╔══╗  ╔╗╔╗╔══╗╔══╗ ╔╗  ╔══╗╔═══╗╔══╗  |\n\r"
    "|  ║║║║║╔╗║║║  ║╔══╝║╚═╝║║╔╗║║║║╔═╝║║║╔═╝║╔═╝  ║║║║║╔═╝║╔╗║ ║║  ║╔╗║║╔═╗║║╔╗║  |\n\r"
    "|  ║║║║║╚╝║║║  ║╚══╗║╔╗ ║║║║║║╚╝║  ║╚╝║  ║╚═╗  ║║║║║╚═╗║╚╝╚╗║║  ║║║║║╚═╝║║╚╝║  |\n\r"
    "|  ║╚╝║║╔╗║║║  ║╔══╝║║╚╗║║║║║║╔╗║  ║╔╗║  ╚═╗║  ║║║║╚═╗║║╔═╗║║║  ║║║║║╔╗╔╝║╔╗║  |\n\r"
    "|  ╚╗╔╝║║║║║╚═╗║╚══╗║║ ║║║╚╝║║║║╚═╗║║║╚═╗╔═╝║  ║╚╝║╔═╝║║╚═╝║║╚═╗║╚╝║║║║║ ║║║║  |\n\r"
    "|   ╚╝ ╚╝╚╝╚══╝╚═══╝╚╝ ╚╝╚══╝╚╝╚══╝╚╝╚══╝╚══╝  ╚══╝╚══╝╚═══╝╚══╝╚══╝╚╝╚╝ ╚╝╚╝  |\n\r"
    "|------------------------------------------------------------------------------|\n\r"
    "| Radio parameters:                                                            |\n\r"
    "|    SF = 10                                                                   |\n\r"
    "|    CR = 4/8                                                                  |\n\r"
    "|    Bandwidth = 250k                                                          |\n\r"
    "|    CRC on                                                                    |\n\r"
    "|    Implicit header                                                           |\n\r"
    "|------------------------------------------------------------------------------|\n\r"
    "| you can use these commands:                                                  |\n\r"
    "|    @send {data with size < 256} - to send smth over LoRa                     |\n\r"
    "|    @help - to call this menu                                                 |\n\r"
    "|    @config terminal echo {true/false} - set uart echo for input              |\n\r"
    "| ctrl+C or ctrl+Z - for undo                                                  |\n\r"
    "|------------------------------------------------------------------------------|\n\r"
    "| when LoRa receives data it will be written to this terminal                  |\n\r"
    "|------------------------------------------------------------------------------|";
uint8_t new_line[] =
    "\n\r@";
uint8_t error_parse[] =
    "\n\r@#cannot parse your command";
uint8_t error_send[] =
    "\n\r@#cannot send text, maybe memory errors";
uint8_t command_send[] =
    "send ";
uint8_t command_help[] =
    "help";
uint8_t config_terminal_echo[] =
    "config terminal echo ";
uint8_t true_str[] =
    "true";
uint8_t false_str[] =
    "false";
#pragma endregion cli

/* USER CODE END Variables */
/* Definitions for DefaultTask */
osThreadId_t DefaultTaskHandle;
const osThreadAttr_t DefaultTask_attributes = {
  .name = "DefaultTask",
  .priority = (osPriority_t) osPriorityLow,
  .stack_size = 128 * 4
};
/* Definitions for UsbSendTask */
osThreadId_t UsbSendTaskHandle;
const osThreadAttr_t UsbSendTask_attributes = {
  .name = "UsbSendTask",
  .priority = (osPriority_t) osPriorityAboveNormal,
  .stack_size = 512 * 4
};
/* Definitions for LoraSendTask */
osThreadId_t LoraSendTaskHandle;
const osThreadAttr_t LoraSendTask_attributes = {
  .name = "LoraSendTask",
  .priority = (osPriority_t) osPriorityAboveNormal,
  .stack_size = 512 * 4
};
/* Definitions for UsbReceiveTask */
osThreadId_t UsbReceiveTaskHandle;
const osThreadAttr_t UsbReceiveTask_attributes = {
  .name = "UsbReceiveTask",
  .priority = (osPriority_t) osPriorityNormal,
  .stack_size = 512 * 4
};
/* Definitions for LoRaReceiveTask */
osThreadId_t LoRaReceiveTaskHandle;
const osThreadAttr_t LoRaReceiveTask_attributes = {
  .name = "LoRaReceiveTask",
  .priority = (osPriority_t) osPriorityNormal,
  .stack_size = 512 * 4
};
/* Definitions for SendLoraQueue */
osMessageQueueId_t SendLoraQueueHandle;
const osMessageQueueAttr_t SendLoraQueue_attributes = {
  .name = "SendLoraQueue"
};
/* Definitions for SendUsbQueue */
osMessageQueueId_t SendUsbQueueHandle;
const osMessageQueueAttr_t SendUsbQueue_attributes = {
  .name = "SendUsbQueue"
};
/* Definitions for UsbMutex */
osMutexId_t UsbMutexHandle;
const osMutexAttr_t UsbMutex_attributes = {
  .name = "UsbMutex"
};
/* Definitions for LoraMutex */
osMutexId_t LoraMutexHandle;
const osMutexAttr_t LoraMutex_attributes = {
  .name = "LoraMutex"
};
/* Definitions for LoraSentEvent */
osEventFlagsId_t LoraSentEventHandle;
const osEventFlagsAttr_t LoraSentEvent_attributes = {
  .name = "LoraSentEvent"
};

/* USER CODE BEGIN FunctionPrototypes */
/*!
 * @brief Function to be executed on Radio Tx Done event
 */
static void OnTxDone(void);

/**
 * @brief Function to be executed on Radio Rx Done event
 * @param  payload ptr of buffer received
 * @param  size buffer size
 * @param  rssi
 * @param  LoraSnr_FskCfo
 */
static void OnRxDone(uint8_t *payload, uint16_t size, int16_t rssi, int8_t LoraSnr_FskCfo);

/**
 * @brief Function executed on Radio Tx Timeout event
 */
static void OnTxTimeout(void);

/**
 * @brief Function executed on Radio Rx Timeout event
 */
static void OnRxTimeout(void);

/**
 * @brief Function executed on Radio Rx Error event
 */
static void OnRxError(void);
#pragma endregion lora_callbacks

/* USER CODE END FunctionPrototypes */

void StartDefaultTask(void *argument);
void StartUsbSendTask(void *argument);
void StartLoraSendTask(void *argument);
void StartUsbReceiveTask(void *argument);
void StartLoraReceiveTask(void *argument);

void MX_FREERTOS_Init(void); /* (MISRA C 2004 rule 8.1) */

/* Hook prototypes */
void vApplicationStackOverflowHook(xTaskHandle xTask, signed char *pcTaskName);

/* USER CODE BEGIN 4 */
void vApplicationStackOverflowHook(xTaskHandle xTask, signed char *pcTaskName)
{
  /* Run time stack overflow checking is performed if
  configCHECK_FOR_STACK_OVERFLOW is defined to 1 or 2. This hook function is
  called if a stack overflow is detected. */
}
/* USER CODE END 4 */
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

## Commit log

2024-07-26 Init commit
    Hardware and docs are ready, software works but is in progress
    [Algorithm.SchDoc, AlhorithgLib.SchLib, Antenna.PcbLib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]
2024-07-27 Rename BOM ЕСКД.xls to BOM.xls
    [BOM.xls]
2024-08-24 improve pcbdoc documentation
2024-08-24 improve doc pcb size

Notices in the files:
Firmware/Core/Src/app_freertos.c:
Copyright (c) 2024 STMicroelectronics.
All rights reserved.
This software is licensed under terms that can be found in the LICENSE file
